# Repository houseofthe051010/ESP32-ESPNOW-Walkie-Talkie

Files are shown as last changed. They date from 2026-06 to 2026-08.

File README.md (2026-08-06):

Source: 

<p align="center">
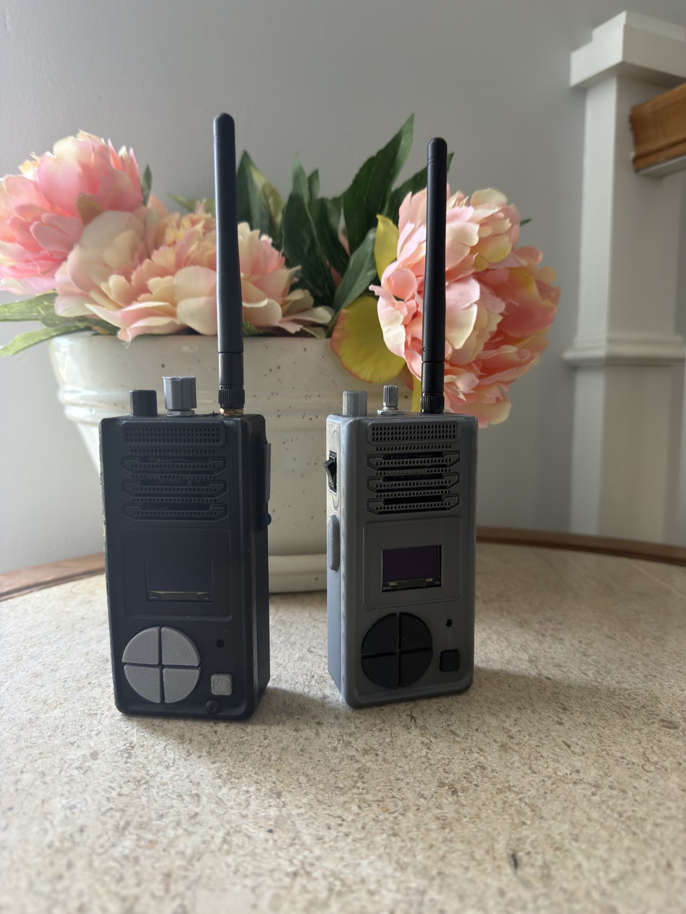
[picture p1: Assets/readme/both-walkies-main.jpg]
Both ESP32 walkie talkies side by side
  
</p>

## The Project

This is a ESP32 walkie talkie that uses WIFi (ESPNOW) for long range communication. It uses the esp32-wroom-32-U with an external U.fl connector, OLED 0.96 I2C display, I2S INMP441 microphone, I2S MAX98357A 3W speaker amplifier, 10k volume potentiometer, PTT button + 5 menu buttons, LASER, and LED. The aim of this walkie talkie was to not just serve as a walkie talkie, but sort of like a custom flipper zero that was more wireless oriented, although the walkie talkie comes with 3 female dupont pins that can be plugged in externally for a UART connection.

This device was framed as a walkie talkie but it can be used as a Wi-Fi/IoT device handheld controller platform. This is the main advantage with WIFI on esp32s as you can connect to a lot of places.

### Features

* ESP-NOW DIRECT VOICE (No router needed, multiple devices can connect)
* U.FL antenna for maximum range
* Tested to 600 meters of distance
* No acknowledge on ESPNOW, just shout and listen
* 16 kHz mono voice capture with IMA ADPCM compression
* No acknowledgement can be a problem with dropped packets so at weak ranges packets are automatically duplicated
* Built in black box logging with telemetry that can be uploaded to computer.
* OLED GUI with many features to control the walkie talkie and use as a remote for other wifi things.

<p align="center">
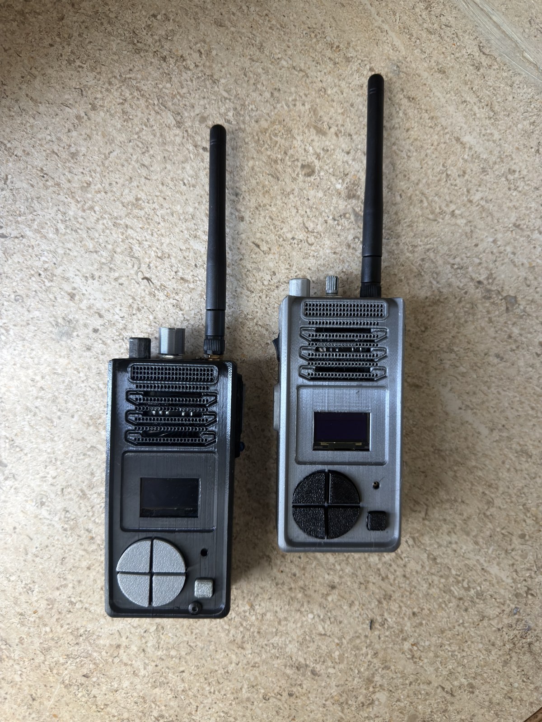
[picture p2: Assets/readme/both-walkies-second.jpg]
Second side-by-side photo of both ESP32 walkie talkies
  
</p>

## Walkie Talkie Hardware

The enclosure was designed to have enough space to solder every wire, but a custom PCB version was also made, scroll all the way down to learn more about fabricating PCB.

<p align="center">
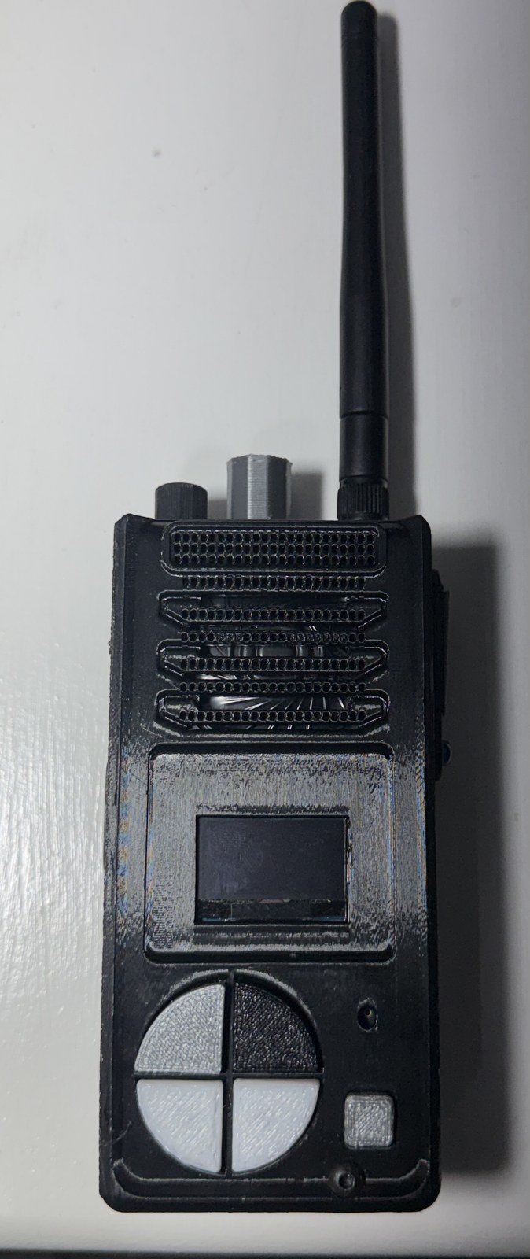
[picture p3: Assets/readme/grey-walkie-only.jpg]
Grey ESP32 walkie talkie
  
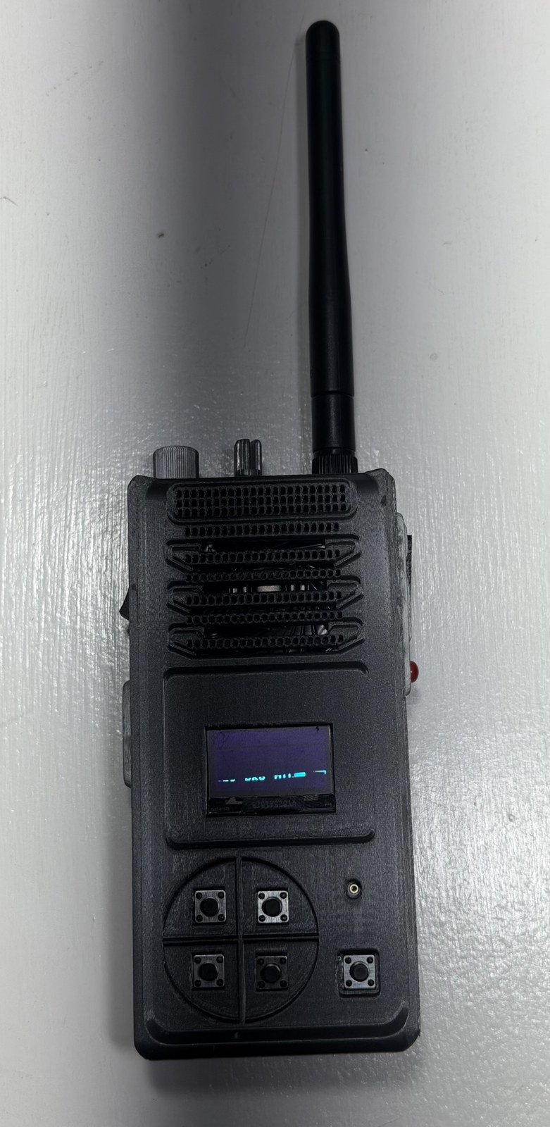
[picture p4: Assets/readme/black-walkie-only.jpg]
Black ESP32 walkie talkie
  
</p>

### Electronics

* ESP32WROOM32 U.FL
* OLED I2C 0.96'
* I2S INMP441 MIC
* 10K Volume potentiometer.
* 2000 MAH LIPO
* 6 push buttons
* 5mm LED light
* 5V laser module
* Voltage divider for ADC battery voltage measurment
* Main power switch

## Assembly Process

### 1. Printed enclosure

All these parts contribute to the final product

* [`walkie_talkie_bottom_case.stl`](SOURCE%20CAD/INDIVIDUAL%20STLS/walkie_talkie_bottom_case.stl)
* [`walkie_talkie_top_cover.stl`](SOURCE%20CAD/INDIVIDUAL%20STLS/walkie_talkie_top_cover.stl)
* [`walkie_talkie_top_buttons_grid.stl`](SOURCE%20CAD/INDIVIDUAL%20STLS/walkie_talkie_top_buttons_grid.stl)
* [`walkie_talkie_OK_button.stl`](SOURCE%20CAD/INDIVIDUAL%20STLS/walkie_talkie_OK_button.stl)
* [`walkie_talkie_PTT_button.stl`](SOURCE%20CAD/INDIVIDUAL%20STLS/walkie_talkie_PTT_button.stl)
* [`walkie_talkie_PTT_button_insert.stl`](SOURCE%20CAD/INDIVIDUAL%20STLS/walkie_talkie_PTT_button_insert.stl)

### 2. Power system

The battery powers the TP4056 which gives power to a boost converter than powers the entire device

1. Wire th TP4056 through the battery to the main switch to the boost convert and then to the esp32 VIN rail.

### 3. Electronics wiring

1. To make it easy and not messy, wire every component listed in the schematic to their respected GPIO and some pins might have multiple wires to them, thats fine.
2. Make sure to use heat shrink tape to avoid short circuits. 

### 4. Front-panel assembly

1. The LED and laser press into their  holes.
2. The PTT, OK, and four navigation buttons sit in the front-panel openings.
3. Insert the OLED
4. Secure all with super glue. Make sure to apply around perimeter and not damage the electronics.

### 5. Internal packing

1. Insert the electronics. One at a type, placing the esp32 underneath the TP4056 mount, and glueing each part to their holes.
2. The enclosure has enough space to accodomate addition UART connections if you want to connect something else later on.

### 6. ESP-IDF firmware loading

1. Fork the project and config with ESP-IDF to upload the code
2. Make sure you have experience with using powershell, open it

3. Init the powershell

   ```powershell
   idf.py set-target esp32
   ```

4. Open project using

   ```powershell
   idf.py menuconfig
   ```

6. Compile using

   ```powershell
   idf.py build
   ```

7. Flash using

   ```powershell
   idf.py flash monitor
   ```

## Circuit Diagram

<p align="center">
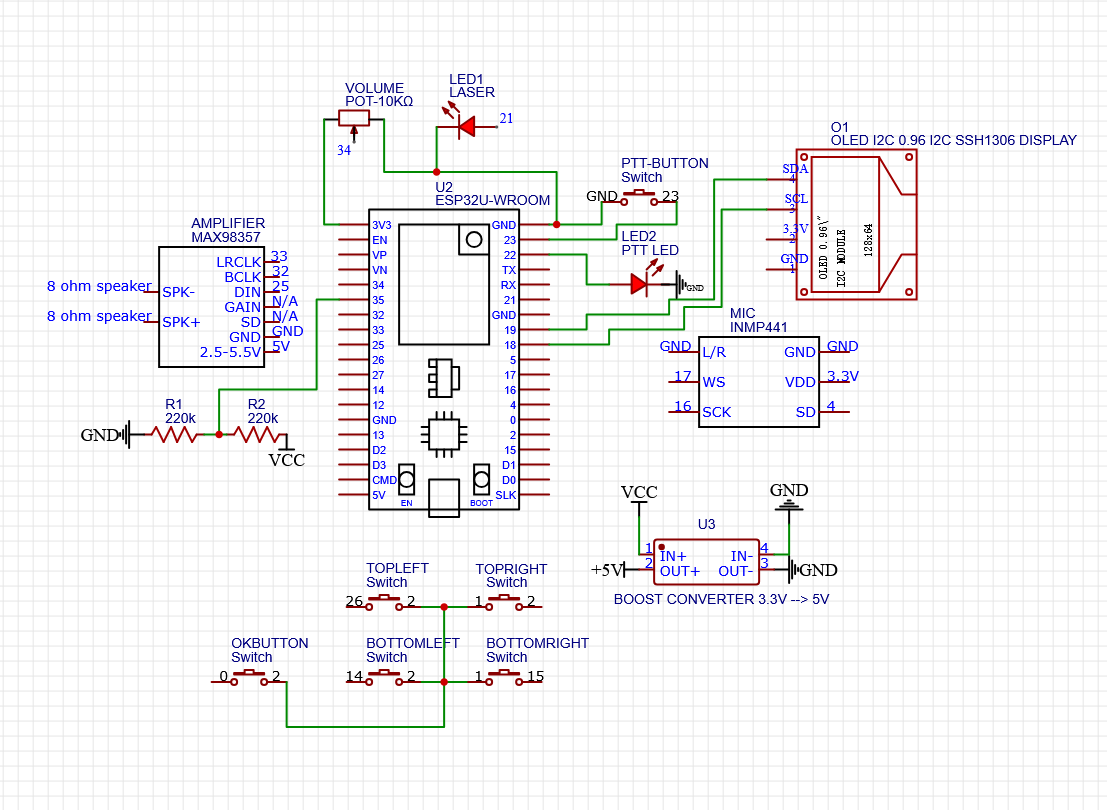
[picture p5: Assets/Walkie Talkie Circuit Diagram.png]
Walkie talkie circuit diagram
  
</p>

### Device PINOUT (Use when soldering)

| Function | ESP32 GPIO |
| --- | ---: |
| OLED SCL | GPIO18 |
| OLED SDA | GPIO19 |
| Speaker BCLK | GPIO32 |
| Speaker WS/LRC | GPIO33 |
| Speaker DIN | GPIO25 |
| Microphone BCLK | GPIO16 |
| Microphone WS | GPIO17 |
| Microphone SD | GPIO4 |
| OK button | GPIO0 |
| Bottom-left button | GPIO14 |
| Bottom-right button  | GPIO15 |
| Laser | GPIO21 |
| Volume potentiometer | GPIO34 |
| Battery divider | GPIO35 |

## My versions:

## Grey Walkie

<p align="center">
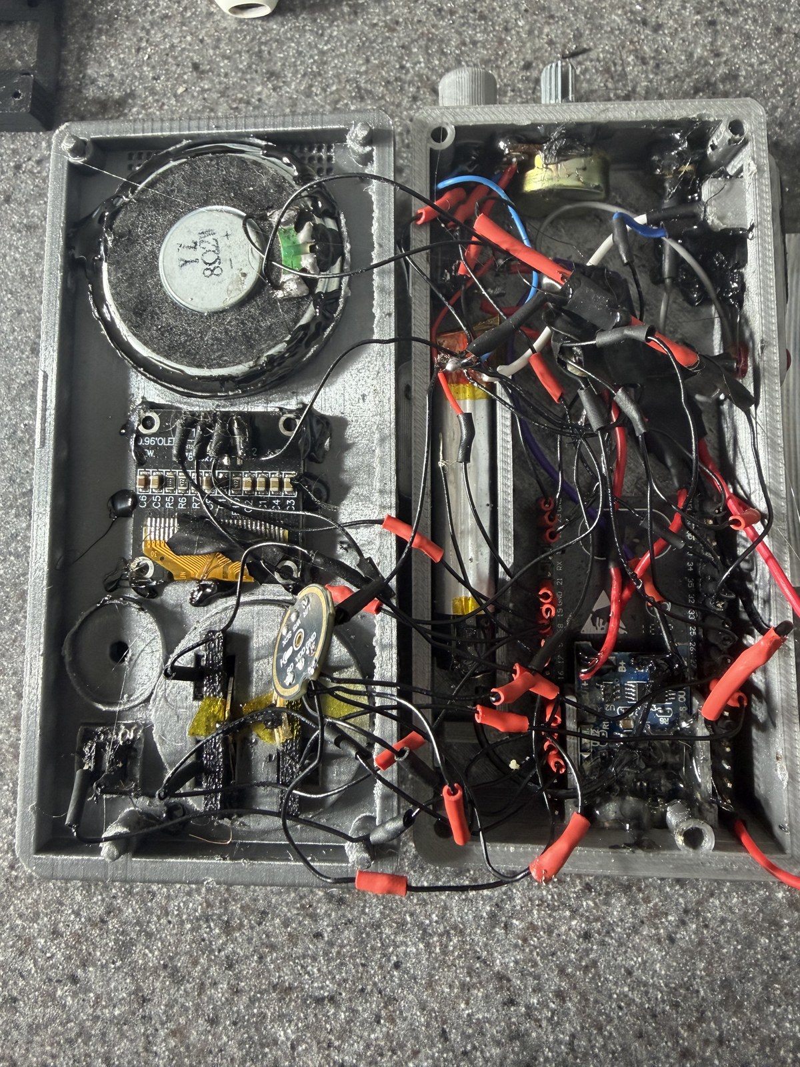
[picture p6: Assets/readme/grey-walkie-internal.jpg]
Grey walkie internal circuitry
  
</p>

This is my 2nd iteration with much cleaner wiring

## Black Walkie

<p align="center">
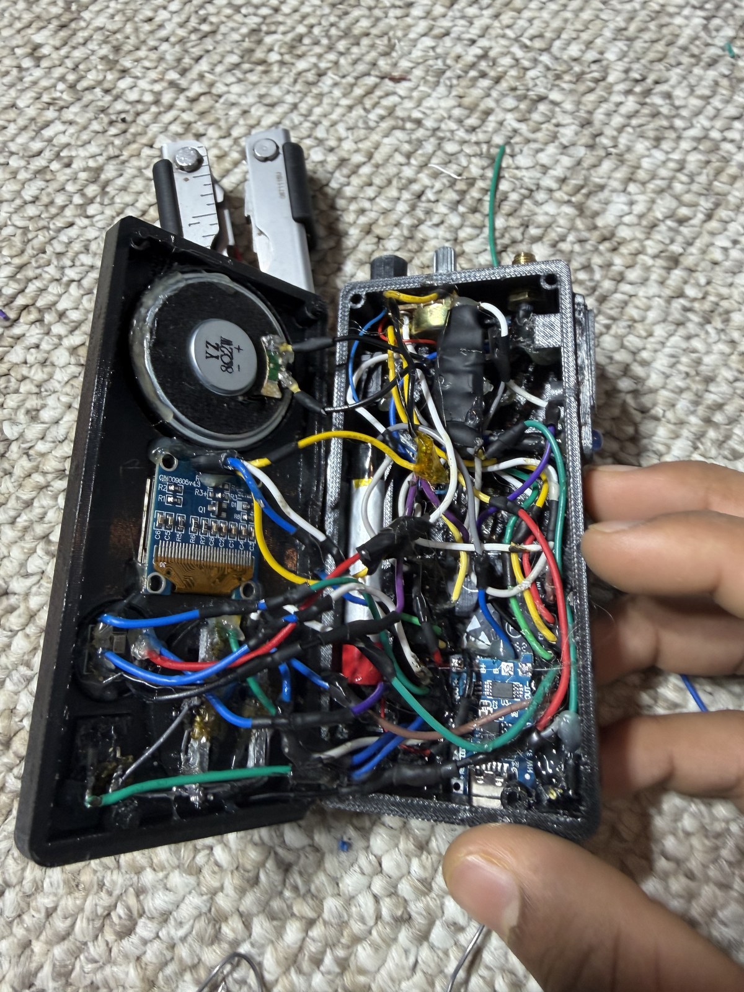
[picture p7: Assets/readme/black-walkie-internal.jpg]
Black walkie internal circuitry
  
</p>

This first iteration is much more messier

### User Interface

The user interface has a whole "apps" menu for different wifi connections and button use cases, you can code your own for your own custom use cases.

<p align="center">
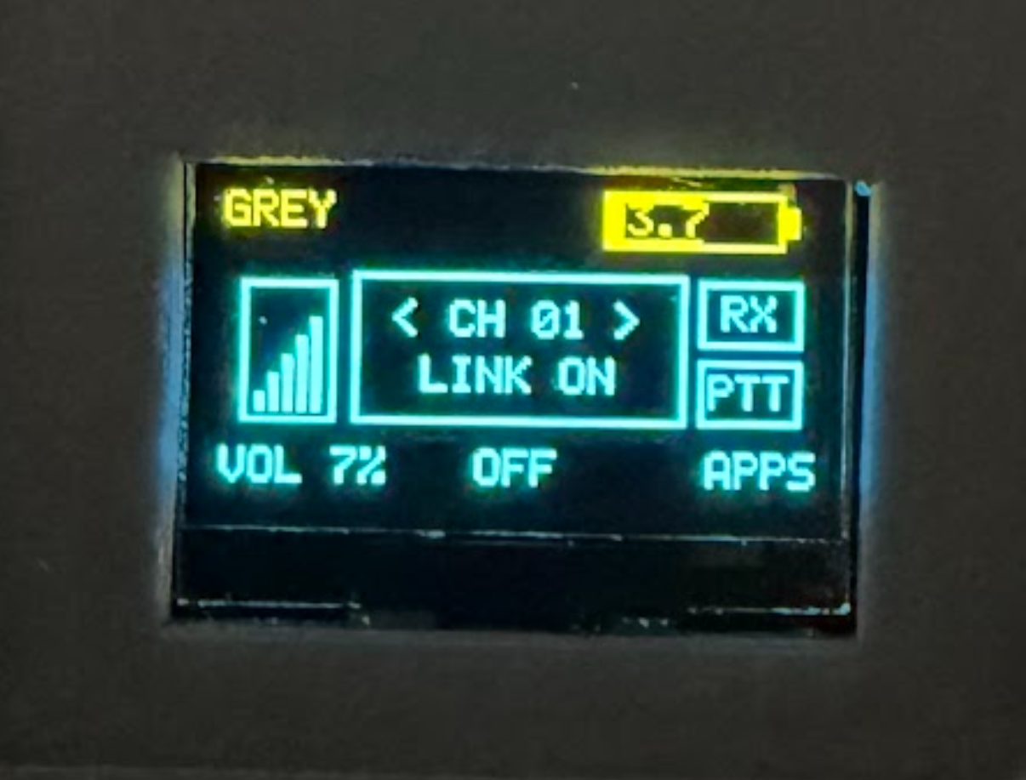
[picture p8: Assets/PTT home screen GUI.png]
Real OLED PTT home screen GUI
  
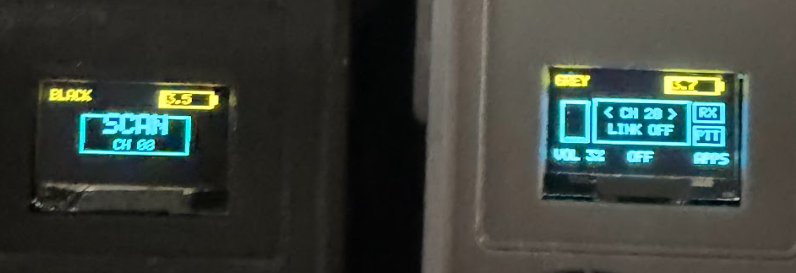
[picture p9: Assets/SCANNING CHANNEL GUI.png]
Real OLED scanning channel GUI
  
</p>

<p align="center">
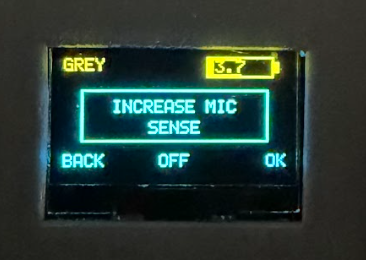
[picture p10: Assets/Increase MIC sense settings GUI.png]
Real OLED increase mic sensitivity settings GUI
  
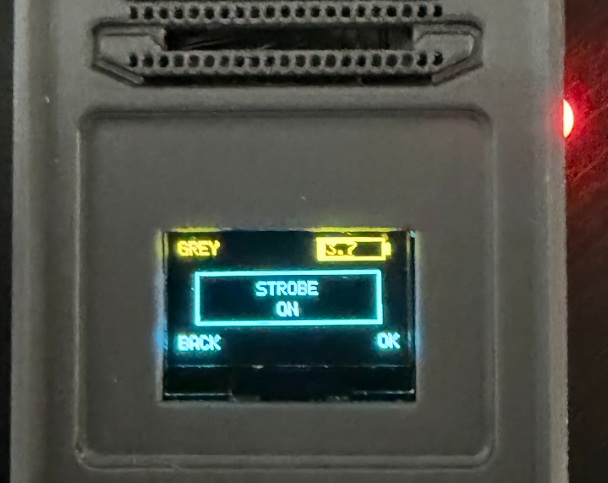
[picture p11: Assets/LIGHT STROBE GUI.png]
Real OLED light strobe app GUI
  
</p>

### Black Box

You can debug or see what happend with the walkie in the field, this isn't really needed now that I have perfected the code though, but can be helpful if you're making your own changes.

Example of a JSON black box record:

```json
{"event":"radio_stats","t_ms":123456,"board":"BLACK","ch":1,"ptt":false,"link":true,"rssi_dbm":-82,"quality_pct":21,"jitter_frames":3,"vol_pct":50,"tx_audio":0,"tx_audio_dup":0,"tx_ctrl":2,"tx_no_mem":0,"tx_fail":0,"rx_audio":48,"rx_audio_dup":7,"rx_audio_old":0,"rx_plc":2,"rx_ctrl":1,"rx_wrong_peer":0,"rx_bad_proto":0,"rx_wrong_channel":0}
```

## Bill of Materials

| Category | Quantity | Part | Purchase Link | Estimated Price |
| --- | ---: | --- | --- | ---: |
| Fabricated  | 2 | Walkie-talkie enclosure | [AliExpress](https://www.aliexpress.us/item/3256806989098121.html) | $2.22 |
| Electronics | 2 | ESP32 development board | [AliExpress](https://www.aliexpress.us/item/3256807617923920.html) | $1.90 |
| Radio | 2 | External antenna | [AliExpress](https://www.aliexpress.us/item/3256812004598286.html) | $0.64 used |
| Display | 2 | 0.96-inch OLED display | [AliExpress](https://www.aliexpress.us/item/3256805954920554.html) | $1.98 used |
| Audio | 2 | I2S microphone | [AliExpress](https://www.aliexpress.us/item/3256810210666726.html) | $6.45 |
| Audio | 2 | I2S speaker amplifier | [AliExpress](https://www.aliexpress.us/item/3256809715431644.html) | $1.88 used |
| Audio | 2 | Speaker | [AliExpress](https://www.aliexpress.us/item/3256805151989671.html) | $0.99 |
| Control | 2 | Volume potentiometer | [AliExpress](https://www.aliexpress.us/item/3256805703535495.html) | $0.99 |
| Power | 2 | Lithium battery | [AliExpress](https://www.aliexpress.us/item/3256811489152615.html) | $10.96 used |
| Power | 2 | Battery charger and protection board | [AliExpress](https://www.aliexpress.us/item/3256809139500038.html) | $0.20 used |
| Power | 2 | Boost converter | [AliExpress](https://www.aliexpress.us/item/3256811757076890.html) | $1.88 used |
| Power | 2 | Main power switch | [AliExpress](https://www.aliexpress.us/item/3256809823421130.html) | $2.37 |
| Lighting | 2 | Status LED | [AliExpress](https://www.aliexpress.us/item/3256807537207911.html) | $0.02 used |
| Lighting | 2 | Laser module | [AliExpress](https://www.aliexpress.us/item/3256808318801769.html) | $0.99 |
| Control | 12 | Momentary pushbutton | [AliExpress](https://www.aliexpress.us/item/3256810479380665.html) | $0.99 |
| Optional RC | 2 | Continuous-rotation servo | [AliExpress](https://www.aliexpress.us/item/3256804365417662.html) | $9.28 |
| Measurement | 2 | 100 kΩ battery-divider resistor | [AliExpress](https://www.aliexpress.us/item/3256802303553096.html) | $0.02 used |
| Measurement | 2 | 220 kΩ battery-divider resistor | [AliExpress](https://www.aliexpress.us/item/3256802303553096.html) | $0.02 used |
| Wiring | 1 | Signal and power wire | [AliExpress](https://www.aliexpress.us/item/3256810394181790.html) | $0.99 allowance |

## Custom PCB Fabrication Option

If you want to avoid the hassle of soldering than fabricate your own PCB here: 

See [CUSTOM PCB FABRICATION/README.md](CUSTOM%20PCB%20FABRICATION/README.md) for the JLBPCB fabrication guide

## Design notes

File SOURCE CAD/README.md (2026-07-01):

# Walkie Talkie CAD Files

This folder is reserved for the open-source mechanical design files for the ESP32 walkie-talkie.

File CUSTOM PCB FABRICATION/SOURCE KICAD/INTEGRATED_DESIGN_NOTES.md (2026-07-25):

# Integrated WalkieTalkie schematic

This revision replaces the ESP32 DevKit, TP4056 breakout and MAX98357A
breakout with manufacturer-assembled components.

## Project files

- `WalkieTalkie.kicad_sch` — main/lower PCBA schematic.
- `WalkieTalkie_Front.kicad_sch` — front/user-interface PCBA schematic.
- `WalkieTalkie_JLCPCB.kicad_sym` — project symbol library imported from
  JLCPCB/EasyEDA part records.
- `WalkieTalkie_JLCPCB.pretty` — matching project footprints.
- `WalkieTalkie_JLCPCB.3dshapes` — imported 3D models.
- `JLCPCB_ASSEMBLY_PARTS.csv` — selected major assembly parts and LCSC IDs.

## Important design behavior

- The ESP32-WROOM-32U contains its own U.FL/IPEX antenna connector.
- USB-C VBUS feeds the TP4056 charger and the system load-sharing path.
- USB D+/D- feed a CH340C USB-to-UART bridge. This revision uses manual
  BOOT and RESET buttons instead of the more failure-prone auto-download
  transistor circuit.
- The TP4056 charge current is set near 500 mA with a 2.4 kOhm PROG resistor.
- DW01A + FS8205A provide single-cell protection.
- TPS63031 provides regulated 3.3 V across the normal single-cell range.
- MAX98357A runs from VSYS. Its two speaker pads are a bridge output; neither
  pad is ground.
- R20-R23 are fitted for the Black firmware mapping. R24-R27 are DNP.
  Reverse those two groups for the Grey mapping.

## Hand-soldered parts

The main schematic intentionally uses large plated solder-wire pads for:

- J4: two speaker wires.
- J5: three potentiometer wires.
- J6: two push-to-talk button wires.
- J7: two external status-LED wires.
- J8: two laser-module wires.

The five face buttons are SMD parts on the front PCB and are intended for
manufacturer assembly.

## Before ordering

The OLED part is wave-solder/high-difficulty and the INMP441 listing may
require Standard PCBA or pre-ordering into the JLCPCB private parts library.
Recheck stock and price when ordering. Confirm all imported footprints against
the current manufacturer datasheets before routing or production.

The older breakout-module PCB files and reports are preserved in
`Previous_Breakout_Draft`. Create fresh PCB files after setting the enclosure
dimensions.

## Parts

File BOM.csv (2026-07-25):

Category | Quantity | Part | Link | Price
Fabricated | 2 | Walkie-talkie enclosure | https://www.aliexpress.us/item/3256806989098121.html | $2.22
Electronics | 2 | ESP32 development board | https://www.aliexpress.us/item/3256807617923920.html | $1.90
Radio | 2 | External antenna | https://www.aliexpress.us/item/3256812004598286.html | $0.64 used
Display | 2 | OLED display | https://www.aliexpress.us/item/3256805954920554.html | $1.98 used
Audio | 2 | I2S microphone | https://www.aliexpress.us/item/3256810210666726.html | $6.45
Audio | 2 | I2S speaker amplifier | https://www.aliexpress.us/item/3256809715431644.html | $1.88 used
Audio | 2 | Speaker | https://www.aliexpress.us/item/3256805151989671.html | $0.99
Control | 2 | Volume potentiometer | https://www.aliexpress.us/item/3256805703535495.html | $0.99
Power | 2 | Lithium battery | https://www.aliexpress.us/item/3256811489152615.html | $10.96 used
Power | 2 | Battery charger and protection board | https://www.aliexpress.us/item/3256809139500038.html | $0.20 used
Power | 2 | Boost converter | https://www.aliexpress.us/item/3256811757076890.html | $1.88 used
Power | 2 | Main power switch | https://www.aliexpress.us/item/3256809823421130.html | $2.37
Lighting | 2 | Status LED | https://www.aliexpress.us/item/3256807537207911.html | $0.02 used
Lighting | 2 | Laser module | https://www.aliexpress.us/item/3256808318801769.html | $0.99
Control | 12 | Momentary pushbutton | https://www.aliexpress.us/item/3256810479380665.html | $0.99
Optional RC | 2 | Continuous-rotation servo | https://www.aliexpress.us/item/3256804365417662.html | $9.28
Measurement | 2 | 100-kilohm battery-divider resistor | https://www.aliexpress.us/item/3256802303553096.html | $0.02 used
Measurement | 2 | 220-kilohm battery-divider resistor | https://www.aliexpress.us/item/3256802303553096.html | $0.02 used
Wiring | 1 | Signal and power wire | https://www.aliexpress.us/item/3256810394181790.html | $0.99 allowance

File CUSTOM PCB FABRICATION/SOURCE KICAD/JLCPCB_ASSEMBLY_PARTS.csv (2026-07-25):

Board | References | Qty | Manufacturer Part | LCSC | Assembly | Notes
Main | U1 | 1 | ESP32-WROOM-32U-N4 | C328062 | SMT | 4 MB ESP32 module with factory U.FL/IPEX antenna socket
Main | J1 | 1 | TYPE-C-31-M-12 | C165948 | SMT | 16-pin USB-C receptacle
Main | U4 | 1 | CH340C | C84681 | SMT | USB-to-UART; no external crystal required
Main | U5 | 1 | TP4056 | C20199357 | SMT | Low-cost ESOP-8 1-cell 4.2 V charger
Main | U6 | 1 | DW01A | C351410 | SMT | Single-cell protection controller
Main | Q1 | 1 | FS8205A | C2830320 | SMT | Back-to-back battery protection MOSFETs
Main | U3 | 1 | ME6211C33M5G-N | C82942 | SMT | 3.3 V regulator dedicated to CH340C
Main | U7 | 1 | TPS63031DSKR | C15516 | SMT | Fixed 3.3 V, 900 mA buck-boost for ESP32 and front board
Main | U8 | 1 | MAX98357AETE+T | C910544 | SMT | 3.2 W I2S class-D amplifier, TQFN-16
Main | J3 | 1 | AFC01-S16FCC-00 | C262272 | SMT | 16-pin 0.5 mm bottom-contact FFC connector
Front | J201 | 1 | AFC01-S16FCC-00 | C262272 | SMT | 16-pin 0.5 mm bottom-contact FFC connector
Front | SW201-SW205 | 5 | TS-1088R-02026 | C455280 | SMT | 4 x 3 mm SMD tactile switch
Front | U202 | 1 | INMP441ACEZ | C9900011556 | SMT | LGA-9 I2S microphone; Standard PCBA/private stock may be required
Front | U201 | 1 | HS96L03W2C03 | C5248080 | Wave/Standard | 0.96-inch 128x64 I2C OLED; wave-solder/high-difficulty assembly
Main | J4-J8 | 5 | Solder wire pads | N/A | Hand solder | Potentiometer, speaker, PTT, LED and laser

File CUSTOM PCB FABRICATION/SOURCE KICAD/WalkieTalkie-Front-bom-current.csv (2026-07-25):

Refs | Value | Footprint | MPN | LCSC | DNP
C201,C203 | 100nF | Capacitor_SMD:C_0603_1608Metric
C202,C204 | 10uF | Capacitor_SMD:C_0805_2012Metric
J201 | MAIN BOARD FFC | WalkieTalkie_JLCPCB:FPC-SMD_P0.50-16P_FGS-XJ-H2.0 | AFC01-S16FCC-00 | C262272
R201,R202 | 4.7k | Resistor_SMD:R_0603_1608Metric |  |  | No
SW201 | OK | WalkieTalkie_JLCPCB:SW-SMD_L3.9-W3.0-P4.45 | TS-1088R-02026 | C455280
SW202 | TOP LEFT | WalkieTalkie_JLCPCB:SW-SMD_L3.9-W3.0-P4.45 | TS-1088R-02026 | C455280
SW203 | TOP RIGHT | WalkieTalkie_JLCPCB:SW-SMD_L3.9-W3.0-P4.45 | TS-1088R-02026 | C455280
SW204 | BOTTOM LEFT | WalkieTalkie_JLCPCB:SW-SMD_L3.9-W3.0-P4.45 | TS-1088R-02026 | C455280
SW205 | BOTTOM RIGHT | WalkieTalkie_JLCPCB:SW-SMD_L3.9-W3.0-P4.45 | TS-1088R-02026 | C455280
U201 | HS96L03W2C03 0.96 OLED | WalkieTalkie_JLCPCB:OLED-TH_L27.8-W27.2-P2.54_C9900033791 | HS96L03W2C03 | C5248080
U202 | INMP441ACEZ | WalkieTalkie_JLCPCB:MID-SMD_L4.7-W3.8_INMP441ACEZ | INMP441ACEZ | C9900011556

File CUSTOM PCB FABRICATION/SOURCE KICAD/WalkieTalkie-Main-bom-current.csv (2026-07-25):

Refs | Value | Footprint | MPN | LCSC | DNP
C1,C2,C11 | 1uF | Capacitor_SMD:C_0805_2012Metric
C3,C6,C12,C14,C16 | 100nF | Capacitor_SMD:C_0603_1608Metric
C4,C5,C7-C10,C13,C15 | 10uF | Capacitor_SMD:C_0805_2012Metric
D1 | SS34 | Diode_SMD:D_SMA | SS34 | C8678
D2 | RED CHARGING | LED_SMD:LED_0603_1608Metric
D3 | GREEN FULL | LED_SMD:LED_0603_1608Metric
J1 | TYPE-C-31-M-12 | WalkieTalkie_JLCPCB:USB-C_SMD-TYPE-C-31-M-12_1 | TYPE-C-31-M-12 | C165948
J2 | BATTERY JST-PH | WalkieTalkie_JLCPCB:CONN-SMD_P2.00_S2B-PH-SM4-TB-LF-SN | S2B-PH-SM4-TB(LF)(SN) | C295747
J3 | FRONT BOARD FFC | WalkieTalkie_JLCPCB:FPC-SMD_P0.50-16P_FGS-XJ-H2.0 | AFC01-S16FCC-00 | C262272
J4 | SPEAKER WIRES | Connector_Wire:SolderWire-0.25sqmm_1x02_P4.2mm_D0.65mm_OD1.7mm_Relief
J5 | 10k POTENTIOMETER | Connector_Wire:SolderWire-0.15sqmm_1x03_P4mm_D0.5mm_OD1.5mm_Relief
J6 | PTT BUTTON | Connector_Wire:SolderWire-0.25sqmm_1x02_P4.2mm_D0.65mm_OD1.7mm_Relief
J7 | EXTERNAL LED | Connector_Wire:SolderWire-0.25sqmm_1x02_P4.2mm_D0.65mm_OD1.7mm_Relief
J8 | LASER WIRES | Connector_Wire:SolderWire-0.25sqmm_1x02_P4.2mm_D0.65mm_OD1.7mm_Relief
L1 | 2.2uH >=2A | Inductor_SMD:L_0805_2012Metric
Q1 | FS8205A | WalkieTalkie_JLCPCB:SOT-23-6_L2.9-W1.6-P0.95-LS2.8-BR | FS8205A | C2830320
Q2 | AO3401A | Package_TO_SOT_SMD:SOT-23 | AO3401A | C15127
Q3 | AO3400A | Package_TO_SOT_SMD:SOT-23 | AO3400A | C20917
R1,R2 | 5.1k | Resistor_SMD:R_0603_1608Metric |  |  | No
R3 | 2.4k (500mA) | Resistor_SMD:R_0603_1608Metric |  |  | No
R4,R5,R7 | 1k | Resistor_SMD:R_0603_1608Metric |  |  | No
R6 | 100R | Resistor_SMD:R_0603_1608Metric |  |  | No
R8,R10,R11 | 10k | Resistor_SMD:R_0603_1608Metric |  |  | No
R9,R12,R15 | 100k | Resistor_SMD:R_0603_1608Metric |  |  | No
R13 | 1M | Resistor_SMD:R_0603_1608Metric |  |  | No
R14 | 330R | Resistor_SMD:R_0603_1608Metric |  |  | No
R20-R23 | 0R BLACK | Resistor_SMD:R_0603_1608Metric |  |  | No
R24-R27 | 0R GREY | Resistor_SMD:R_0603_1608Metric |  |  | Yes
R28,R29 | 220k | Resistor_SMD:R_0603_1608Metric |  |  | No
SW1 | RESET | WalkieTalkie_JLCPCB:SW-SMD_L3.9-W3.0-P4.45 | TS-1088R-02026 | C455280
SW2 | BOOT | WalkieTalkie_JLCPCB:SW-SMD_L3.9-W3.0-P4.45 | TS-1088R-02026 | C455280
U1 | ESP32-WROOM-32U-N4 | WalkieTalkie_JLCPCB:WIFIM-SMD_38P-L19.2-W18.0-P1.27 | ESP32-WROOM-32U-N4 | C328062
U2 | USBLC6-2SC6 | Package_TO_SOT_SMD:SOT-23-6 | USBLC6-2SC6 | C7519
U3 | ME6211C33M5G-N | WalkieTalkie_JLCPCB:SOT-23-5_L3.0-W1.7-P0.95-LS2.8-BL | ME6211C33M5G-N | C82942
U4 | CH340C | WalkieTalkie_JLCPCB:SOP-16_L10.0-W3.9-P1.27-LS6.0-BL | CH340C | C84681
U5 | TP4056 | WalkieTalkie_JLCPCB:ESOP-8_L4.9-W3.9-P1.27-LS6.0-BL-EP-4 | TP4056 | C20199357
U6 | DW01A | WalkieTalkie_JLCPCB:SOT-23-6_L2.9-W1.6-P0.95-LS2.8-BL | DW01A | C351410
U7 | TPS63031DSKR | WalkieTalkie_JLCPCB:SON-10_L2.5-W2.5-P0.50-TL-EP | TPS63031DSKR | C15516
U8 | MAX98357AETE+T | WalkieTalkie_JLCPCB:TQFN-16_L3.0-W3.0-P0.50-BL-EP1.5 | MAX98357AETE+T | C910544

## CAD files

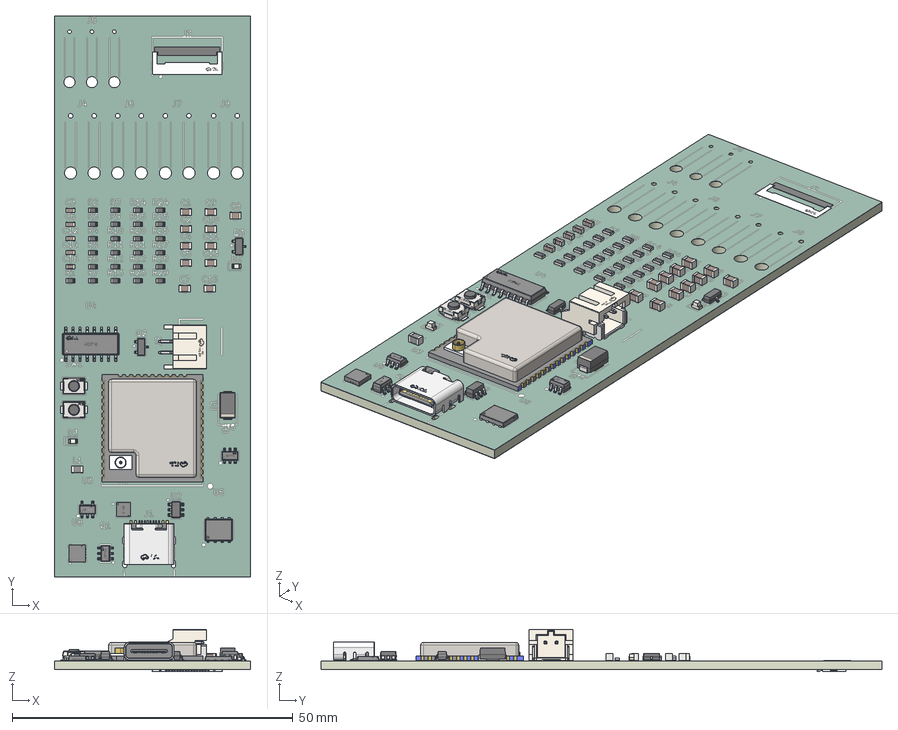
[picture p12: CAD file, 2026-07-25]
CUSTOM PCB FABRICATION/SOURCE KICAD/walkiemainbaord.step
35.0 x 100.0 x 7.50 mm
C_0805_2012Metric x 11
FPC-SMD_P0.50-16P_FGS-XJ-H2.0
R_0603_1608Metric x 25
TQFN-16_L3.0-W3.0-P0.50-BL-EP1.5
SON-10_L2.5-W2.5-H0.8-P0.50
SOT-23 x 2
LED_0603_1608Metric x 2
C_0603_1608Metric x 5
SW-SMD_L3.9-W2.9-H2.0-LS4.8 x 2
SOT-23-6_L2.9-W1.6-H1.5-LS2.8-P0.95 x 2
L_0805_2012Metric
SOP-16_L9.9-W3.9-H1.5-LS6.0-P1.27
WIFIM-SMD_38P-L19.2-W18.0-H3.2-P1.27
USB-C_SMD-TYPE-C-31-M-12
SOT-23-6
D_SMA
SOT-23-5_L2.9-W1.6-H1.1-LS2.8-P0.95
CONN-SMD_P2.00_S2B-PH-SM4-TB-LF-SN
ESOP-8_L4.9-W3.9-P1.27-LS6.0-BL-EP-4
WalkieTalkie_silkscreen
WalkieTalkie_soldermask x 2
WalkieTalkie_PCB

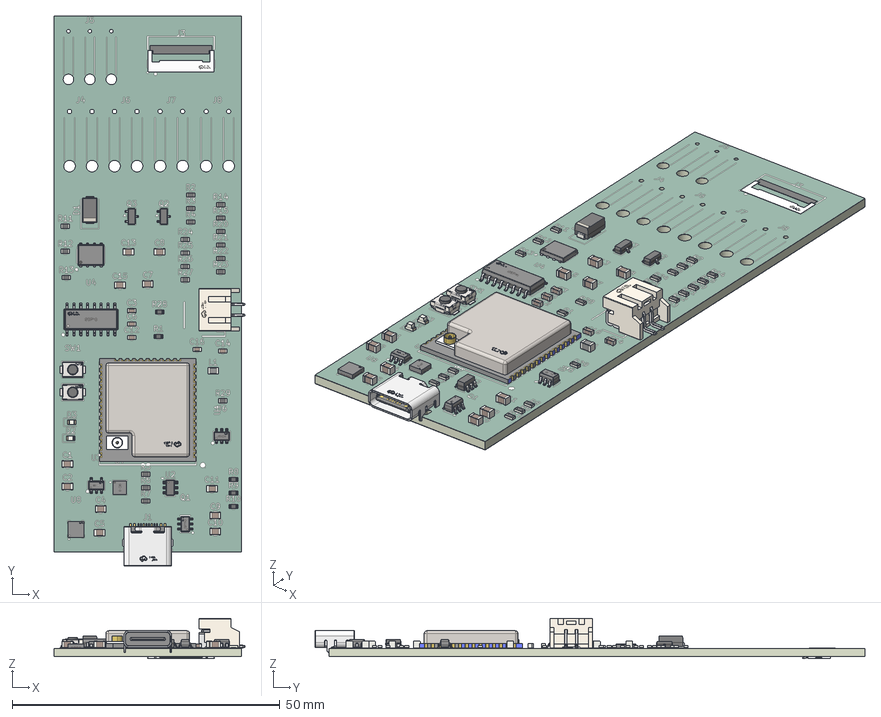
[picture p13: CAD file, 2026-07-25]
CUSTOM PCB FABRICATION/SOURCE KICAD/walkie2mainbaord.step
35.6 x 102.6 x 7.50 mm
C_0805_2012Metric x 11
FPC-SMD_P0.50-16P_FGS-XJ-H2.0
R_0603_1608Metric x 25
TQFN-16_L3.0-W3.0-P0.50-BL-EP1.5
SON-10_L2.5-W2.5-H0.8-P0.50
SOT-23 x 2
LED_0603_1608Metric x 2
C_0603_1608Metric x 5
SW-SMD_L3.9-W2.9-H2.0-LS4.8 x 2
SOT-23-6_L2.9-W1.6-H1.5-LS2.8-P0.95 x 2
L_0805_2012Metric
SOP-16_L9.9-W3.9-H1.5-LS6.0-P1.27
WIFIM-SMD_38P-L19.2-W18.0-H3.2-P1.27
USB-C_SMD-TYPE-C-31-M-12
SOT-23-6
D_SMA
SOT-23-5_L2.9-W1.6-H1.1-LS2.8-P0.95
CONN-SMD_P2.00_S2B-PH-SM4-TB-LF-SN
ESOP-8_L4.9-W3.9-P1.27-LS6.0-BL-EP-4
Wal8574_silkscreen
Wal8574_soldermask x 2
Wal8574_PCB

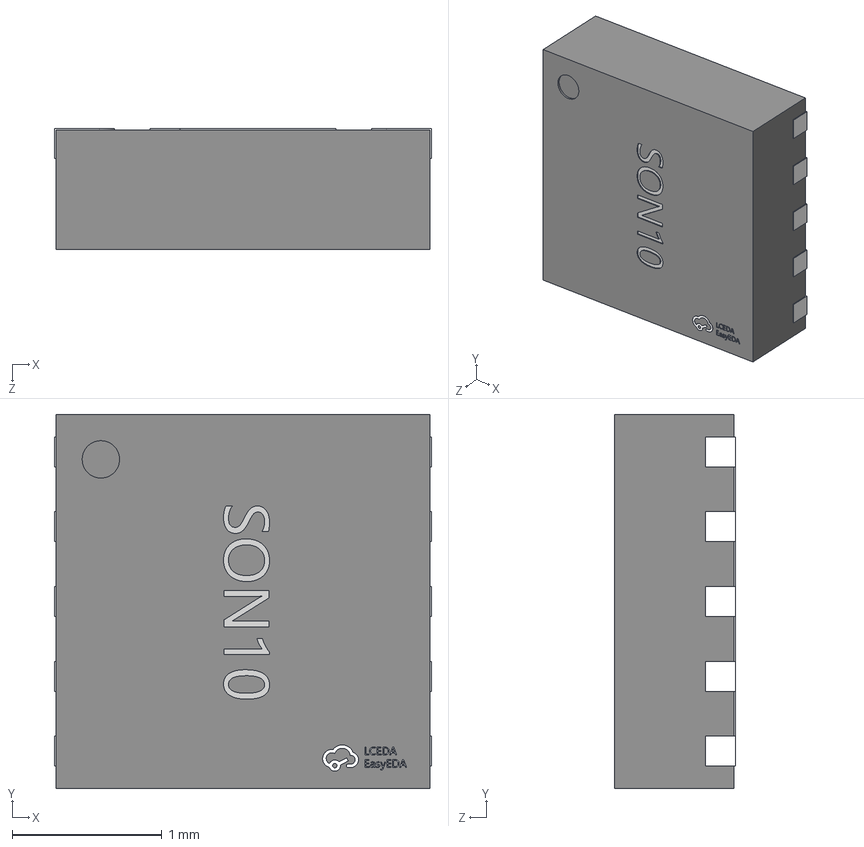
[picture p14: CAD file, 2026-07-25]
CUSTOM PCB FABRICATION/SOURCE KICAD/.easyeda_cache/12c631ea46604e478703d8e42e76d1d7.step
2.52 x 2.50 x 0.811 mm

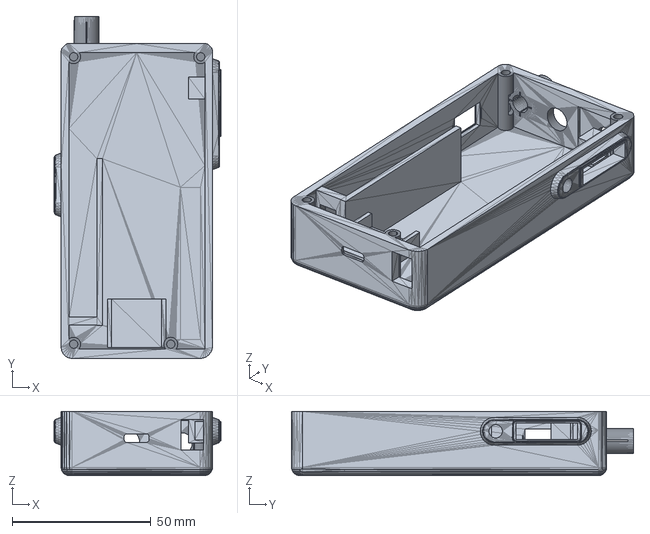
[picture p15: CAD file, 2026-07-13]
SOURCE CAD/INDIVIDUAL STLS/walkie_talkie_bottom_case.step
60.0 x 123.2 x 23.2 mm

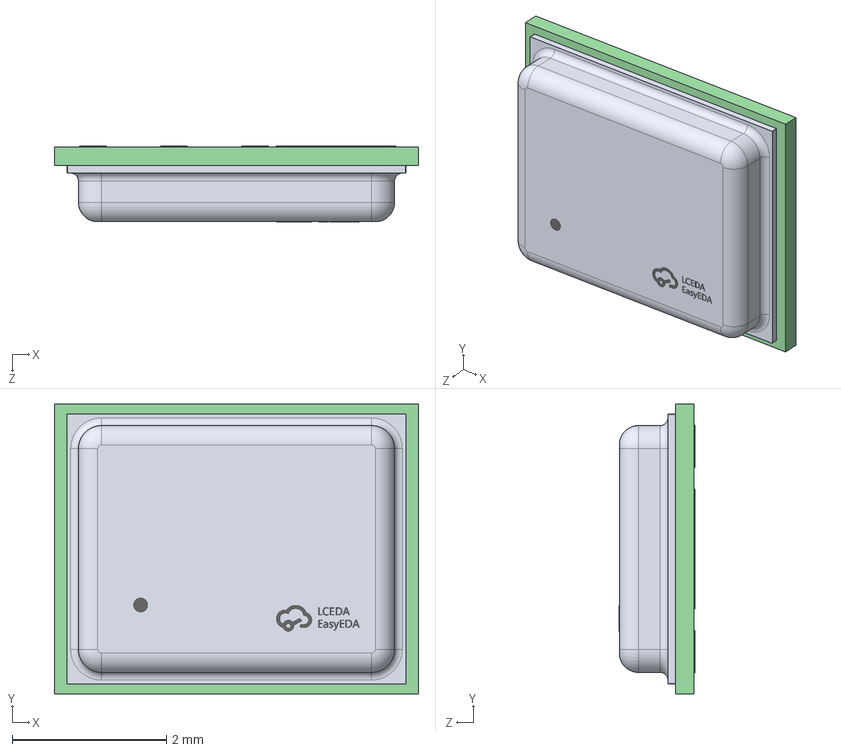
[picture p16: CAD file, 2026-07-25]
CUSTOM PCB FABRICATION/SOURCE KICAD/.easyeda_cache/c35e8a98ac4c4d8d9f4a5ff38194d268.step
4.72 x 3.76 x 0.981 mm

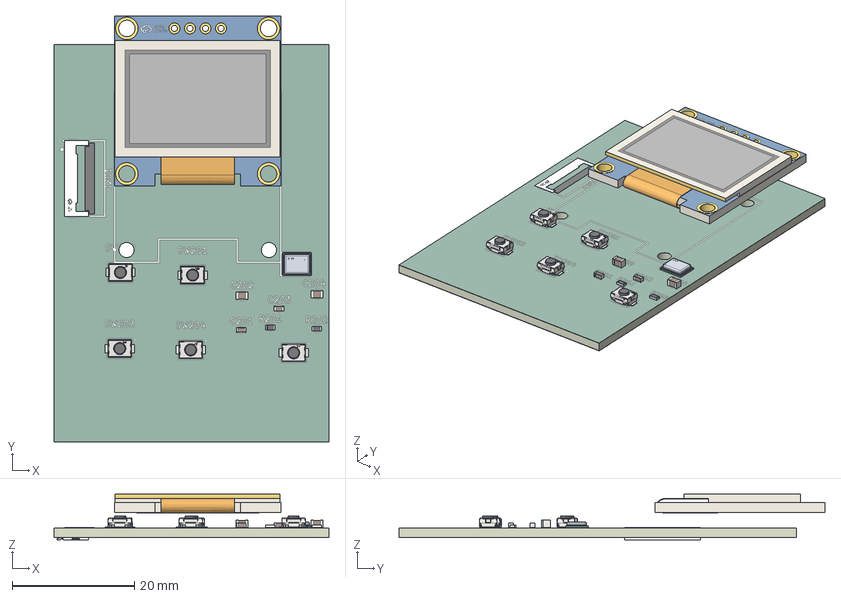
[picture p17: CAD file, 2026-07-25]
CUSTOM PCB FABRICATION/SOURCE KICAD/walkiefront.step
45.0 x 69.6 x 7.50 mm
OLED-TH_L27.8-W27.2-P2.54_C9900033791
C_0805_2012Metric x 2
SW-SMD_L3.9-W2.9-H2.0-LS4.8 x 5
R_0603_1608Metric x 2
FPC-SMD_P0.50-16P_FGS-XJ-H2.0
MID-SMD_L4.7-W3.8_INMP441ACEZ
C_0603_1608Metric x 2
Wal8ED3_silkscreen
Wal8ED3_soldermask x 2
Wal8ED3_PCB

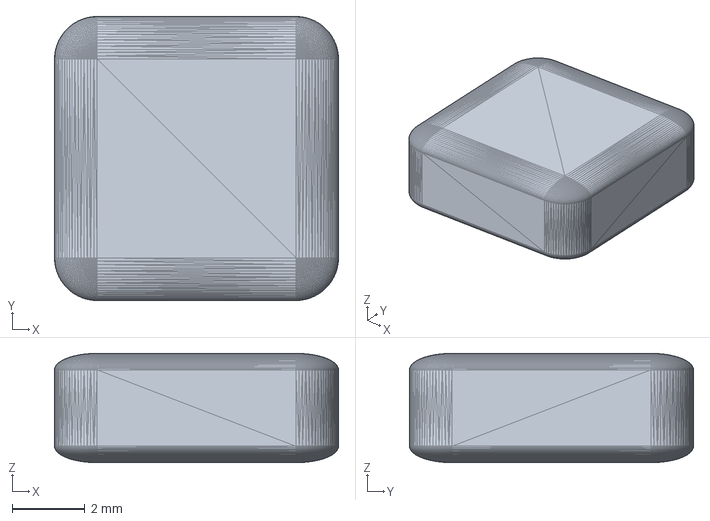
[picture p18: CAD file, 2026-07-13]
SOURCE CAD/INDIVIDUAL STLS/walkie_talkie_OK_button.step
7.80 x 7.80 x 3.00 mm

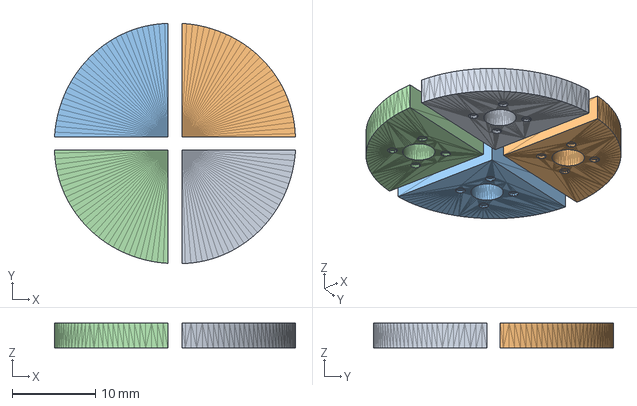
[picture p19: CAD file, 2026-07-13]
SOURCE CAD/INDIVIDUAL STLS/walkie_talkie_top_buttons_grid.step
29.0 x 28.9 x 3.00 mm

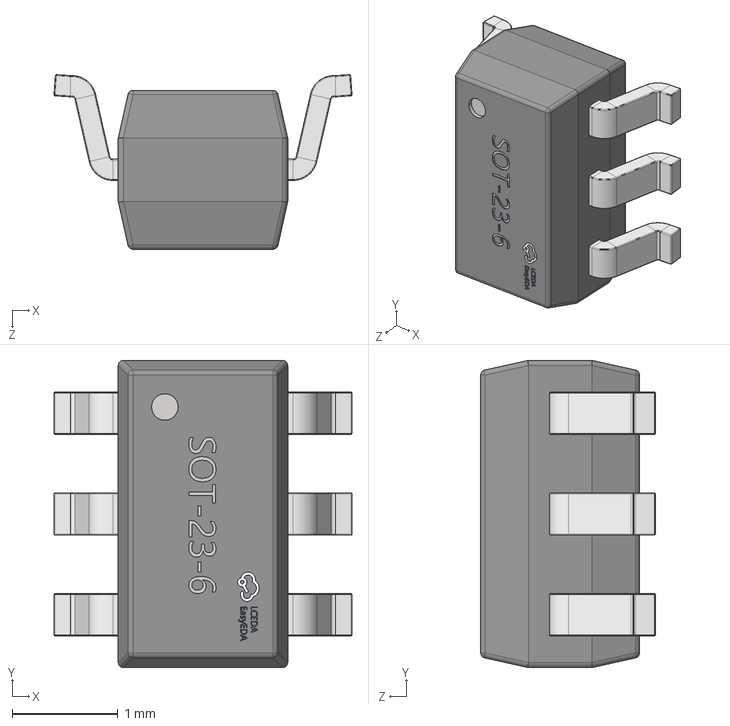
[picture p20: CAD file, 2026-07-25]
CUSTOM PCB FABRICATION/SOURCE KICAD/.easyeda_cache/229b69761e2c45dba6a83d8866dec72d.step
2.81 x 2.90 x 1.65 mm

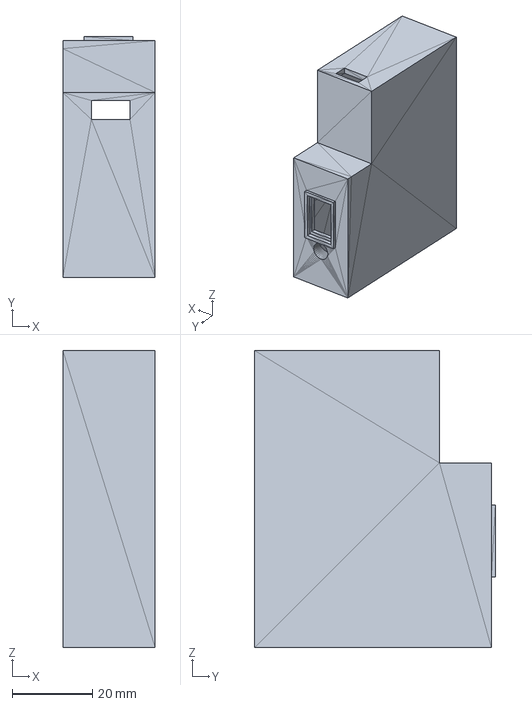
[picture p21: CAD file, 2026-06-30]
SOURCE CAD/INDIVIDUAL STLS/mnbvcx.step
23.0 x 60.0 x 74.0 mm

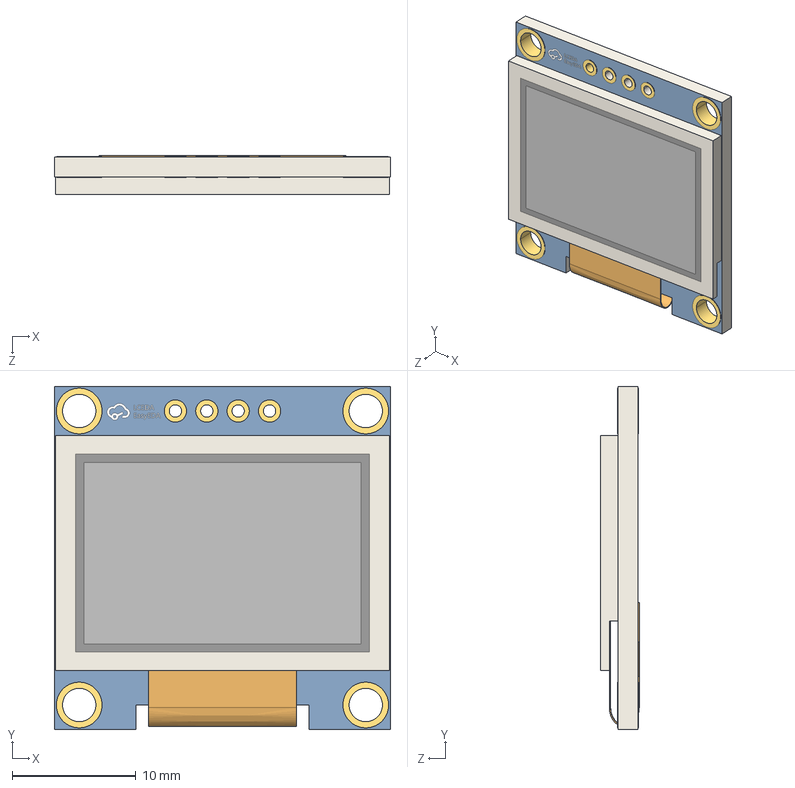
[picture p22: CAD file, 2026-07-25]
CUSTOM PCB FABRICATION/SOURCE KICAD/.easyeda_cache/c6b423183c2f4cf5a163f75f8ad52fae.step
27.2 x 27.8 x 3.12 mm

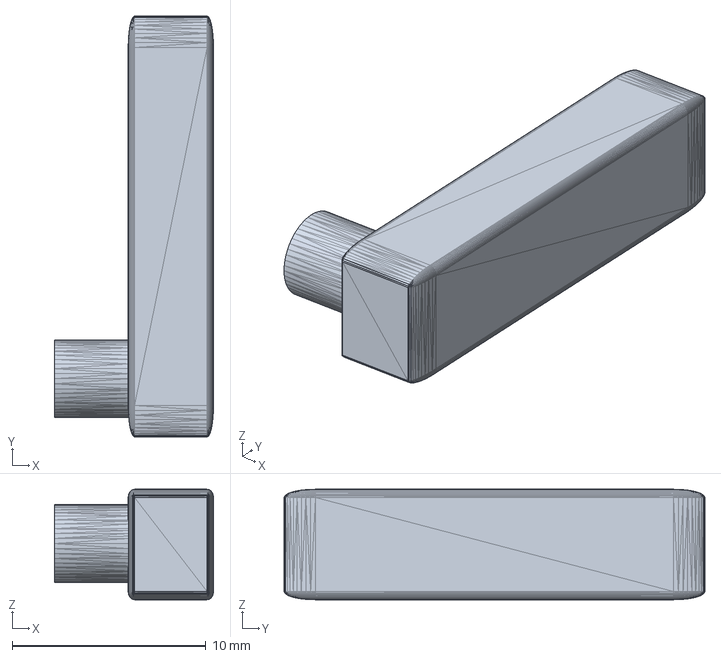
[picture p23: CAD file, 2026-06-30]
SOURCE CAD/INDIVIDUAL STLS/walkie_talkie_PTT_button.step
8.20 x 21.7 x 5.70 mm

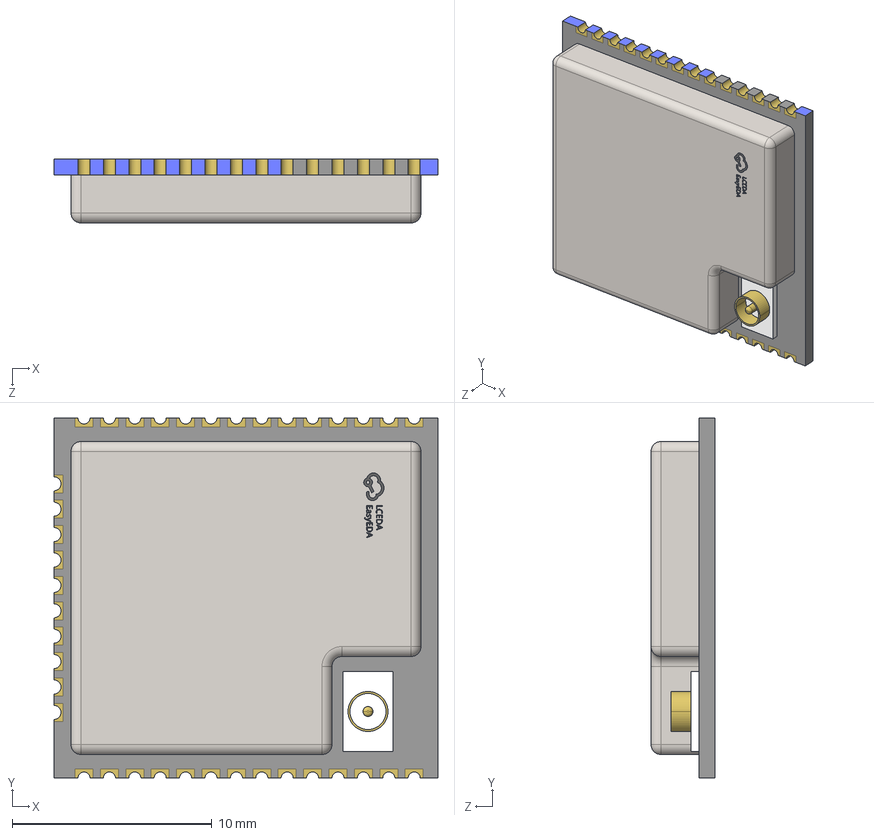
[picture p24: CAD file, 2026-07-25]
CUSTOM PCB FABRICATION/SOURCE KICAD/.easyeda_cache/4bfedb4f78ee4d6a8d7a8c81210d6f34.step
19.2 x 18.0 x 3.20 mm

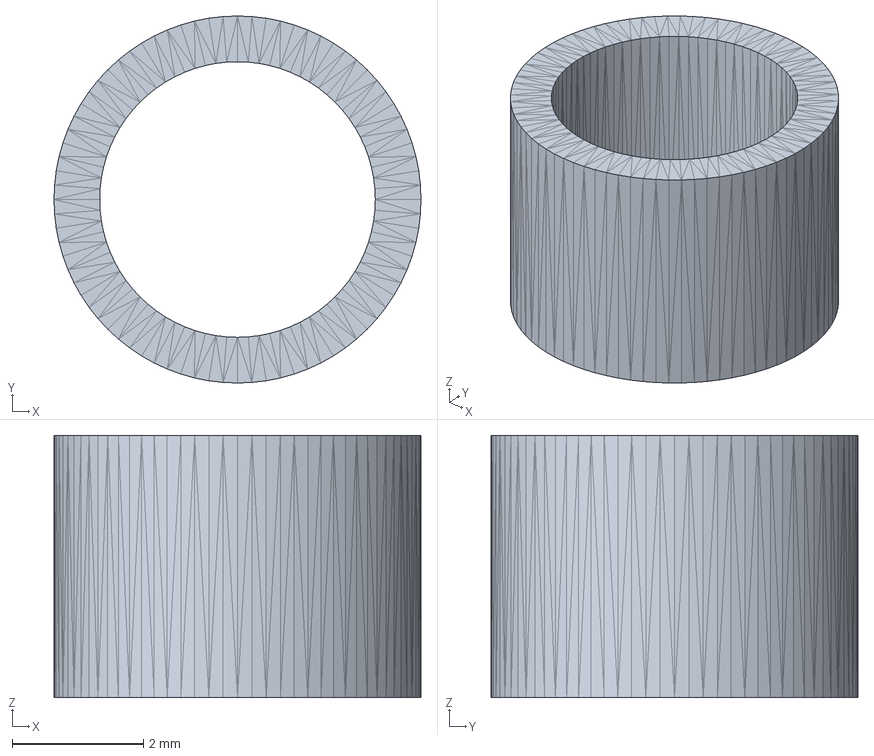
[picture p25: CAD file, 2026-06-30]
SOURCE CAD/INDIVIDUAL STLS/walkie_talkie_PTT_button_insert.step
5.60 x 5.60 x 4.00 mm

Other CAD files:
CUSTOM PCB FABRICATION/SOURCE KICAD/.easyeda_cache/617b05f9bba7410b96c001093d8189e4.step
SOURCE CAD/INDIVIDUAL STLS/walkie_talkie_top_cover.stl
CUSTOM PCB FABRICATION/SOURCE KICAD/.easyeda_cache/10d570588d4c4ccca30b4bf25476f535.step
CUSTOM PCB FABRICATION/SOURCE KICAD/.easyeda_cache/ea3d09bd0a8e416194da70a34a37168f.step
CUSTOM PCB FABRICATION/SOURCE KICAD/.easyeda_cache/07126628bc464d5389bb996c52812f54.obj
CUSTOM PCB FABRICATION/SOURCE KICAD/.easyeda_cache/07126628bc464d5389bb996c52812f54.step
CUSTOM PCB FABRICATION/SOURCE KICAD/.easyeda_cache/10d570588d4c4ccca30b4bf25476f535.obj
CUSTOM PCB FABRICATION/SOURCE KICAD/.easyeda_cache/12c631ea46604e478703d8e42e76d1d7.obj
CUSTOM PCB FABRICATION/SOURCE KICAD/.easyeda_cache/229b69761e2c45dba6a83d8866dec72d.obj
CUSTOM PCB FABRICATION/SOURCE KICAD/.easyeda_cache/2e35dca8e7854ed683469f8d54d1ef17.obj
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

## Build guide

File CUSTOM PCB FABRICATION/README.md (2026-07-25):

# Custom PCB Fabrication

This is a KiCad PCB for those looking to make the walkie talkie from PCBs. Note that you will still have to solder some components.

## PCB Preview

Main board:

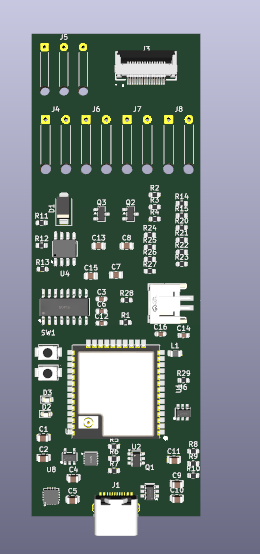
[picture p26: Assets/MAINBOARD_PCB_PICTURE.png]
Main board PCB preview


Front/user-interface board:

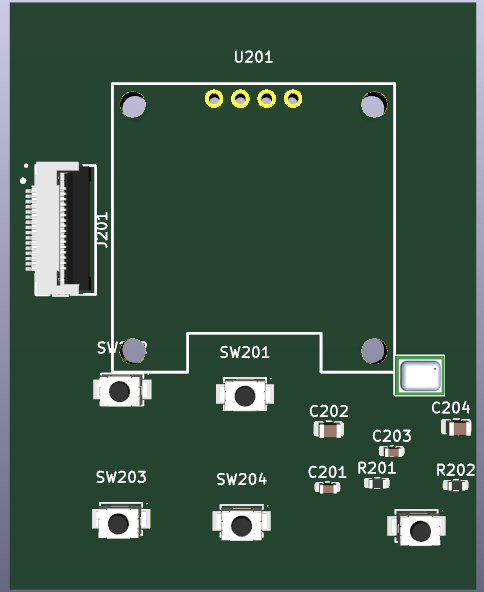
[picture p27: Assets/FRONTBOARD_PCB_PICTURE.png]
Front board PCB preview


## Risks

Although this custom PCB works, I will be manufactering a redesigned much cleaner version later that avoids the hassle of 2 PCB boards and does everything one one, with a much slimmer walkie talkie design.

## Manufacturer Files

In this folder are the source kicad files for the PCB and manufacterable GERBER files.

### Main PCB

- [Gerber/drill ZIP](MANUFACTOR%20FILES/MAIN%20PCB/WalkieTalkie_Main_Gerbers_Drill.zip)
- [JLCPCB BOM CSV](MANUFACTOR%20FILES/MAIN%20PCB/WalkieTalkie_Main_JLCPCB_BOM.csv)
- [JLCPCB CPL / position CSV](MANUFACTOR%20FILES/MAIN%20PCB/WalkieTalkie_Main_JLCPCB_CPL.csv)

### Front PCB

- [Gerber/drill ZIP](MANUFACTOR%20FILES/FRONT%20PCB/WalkieTalkie_Front_Gerbers_Drill.zip)
- [JLCPCB BOM CSV](MANUFACTOR%20FILES/FRONT%20PCB/WalkieTalkie_Front_JLCPCB_BOM.csv)
- [JLCPCB CPL / position CSV](MANUFACTOR%20FILES/FRONT%20PCB/WalkieTalkie_Front_JLCPCB_CPL.csv)

## Parts JLCPCB Can Usually Assemble

Most of the parts and SMD components should be assembled by JLBPCB but you will need to solder these parts:

- PTT Button
- Laser module
- 10K volume potentiometer
- OLED display
- Slim 3W speaker
- Battery
- Power switch

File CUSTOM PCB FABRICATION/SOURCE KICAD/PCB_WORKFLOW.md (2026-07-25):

# Converting the two schematics into PCBs

Create a fresh PCB for each schematic. Do not reuse the archived breakout-board
layouts because their footprints and power architecture are different.

## Main board

1. Open `WalkieTalkie.kicad_pro`, then open `WalkieTalkie.kicad_sch`.
2. Run **Inspect > Electrical Rules Checker**. The imported EasyEDA symbols use
   `Unspecified` pin types, so KiCad reports `pin_to_pin` warnings. Check for
   actual red errors rather than automatically excluding everything.
3. Open **Tools > Assign Footprints**. Confirm every project-library footprint
   resolves through `WalkieTalkie_JLCPCB.pretty`.
4. Select **Tools > Update PCB from Schematic** or press **F8**.
5. When KiCad asks for a board, create and save a new
   `WalkieTalkie_Main.kicad_pcb`.
6. Draw the measured casing outline on `Edge.Cuts`. Add mounting holes, USB-C
   opening, U.FL access, battery clearance and cable-clearance areas before
   placing electrical parts.
7. Place the mechanical parts first: USB-C, ESP32/U.FL edge, battery connector,
   FFC connector and J4-J8 solder pads. Then place regulators and decoupling
   parts tightly around their ICs.

## Front board

1. Open `WalkieTalkie_Front.kicad_pro`, then
   `WalkieTalkie_Front.kicad_sch`.
2. Press **F8** and save a new `WalkieTalkie_Front.kicad_pcb`.
3. Draw the front-board outline from the casing.
4. Enter the exact button-center coordinates, OLED viewing-window location and
   microphone opening before placing the remaining parts.
5. Put a board cutout/acoustic hole directly under the INMP441 port. Verify the
   imported microphone footprint and its pin-1 orientation against the current
   datasheet.

## Routing rules

- Prefer four layers: front signals/components, solid ground, power, rear
  signals/components.
- Route USB D+/D- as a short, length-matched 90-ohm differential pair. Use the
  impedance dimensions supplied by the PCB manufacturer.
- Keep TPS63031 input/output capacitors and inductor beside U7. Minimize both
  switching-current loops.
- Route battery, VSYS and speaker paths with wide copper. Neither MAX98357A
  speaker output is ground.
- Use a solid ground plane beneath the ESP32 module, but keep antenna coax and
  the external antenna away from switching and speaker-current paths.
- Put thermal/ground vias in the TP4056, TPS63031 and MAX98357A exposed pads as
  required by their datasheets.
- Keep I2S traces short and referenced to continuous ground.

## Final checks and JLCPCB files

1. Run **Inspect > Design Rules Checker** until there are no shorts, clearance
   errors, unconnected nets or invalid board-edge errors.
2. Inspect both boards in the 3D Viewer. Confirm connector direction, FFC
   contact side, OLED orientation, button height and enclosure clearances.
3. Generate Gerbers and drill files from **File > Fabrication Outputs**.
4. Generate the component position file for both boards. JLCPCB usually expects
   reference, X, Y, layer and rotation fields.
5. Export a BOM containing the schematic `LCSC` field. Use
   `JLCPCB_ASSEMBLY_PARTS.csv` as the selected-part reference.
6. Recheck JLCPCB stock before ordering. The OLED and INMP441 may require
   Standard PCBA, pre-ordering or a manually sourced substitute.

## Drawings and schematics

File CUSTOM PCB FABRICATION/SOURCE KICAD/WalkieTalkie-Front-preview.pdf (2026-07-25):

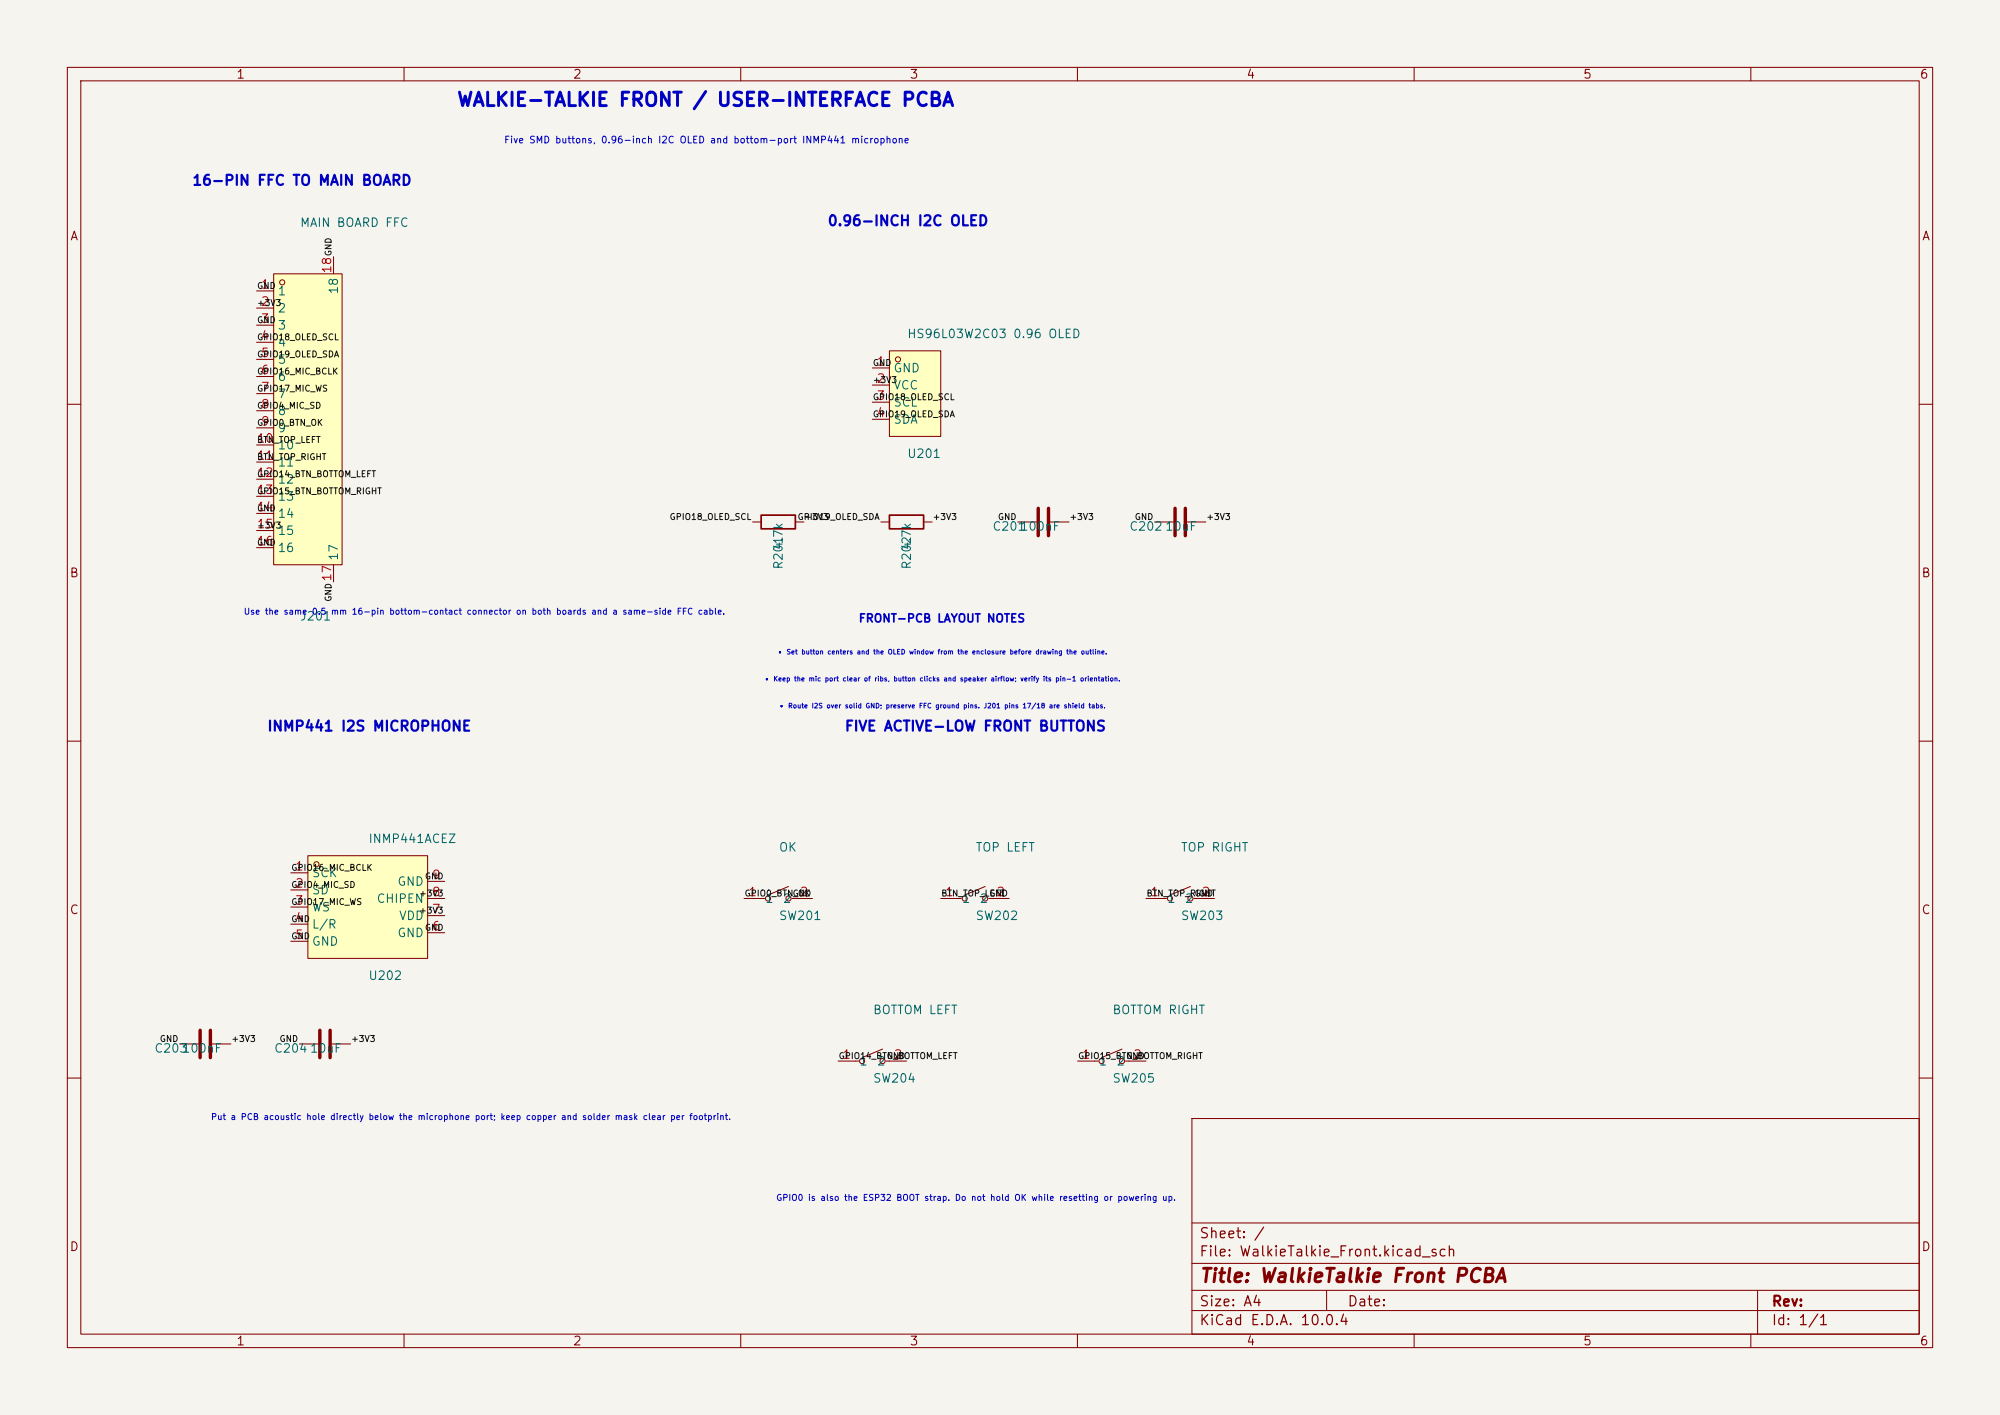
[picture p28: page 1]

16-PIN FFC TO MAIN BOARD

• Route I2S over solid GND; preserve FFC ground pins. J201 pins 17/18 are shield tabs. FIVE ACTIVE-LOW FRONT BUTTONS

Put a PCB acoustic hole directly below the microphone port; keep copper and solder mask clear per footprint.

GPIO0 is also the ESP32 BOOT strap. Do not hold OK while resetting or powering up.

Sheet: /
File: WalkieTalkie_Front.kicad_sch
Title: WalkieTalkie Front PCBA

Size: A4 | Rev:
KiCad E.D.A. 10.0.4 | Id: 1/1

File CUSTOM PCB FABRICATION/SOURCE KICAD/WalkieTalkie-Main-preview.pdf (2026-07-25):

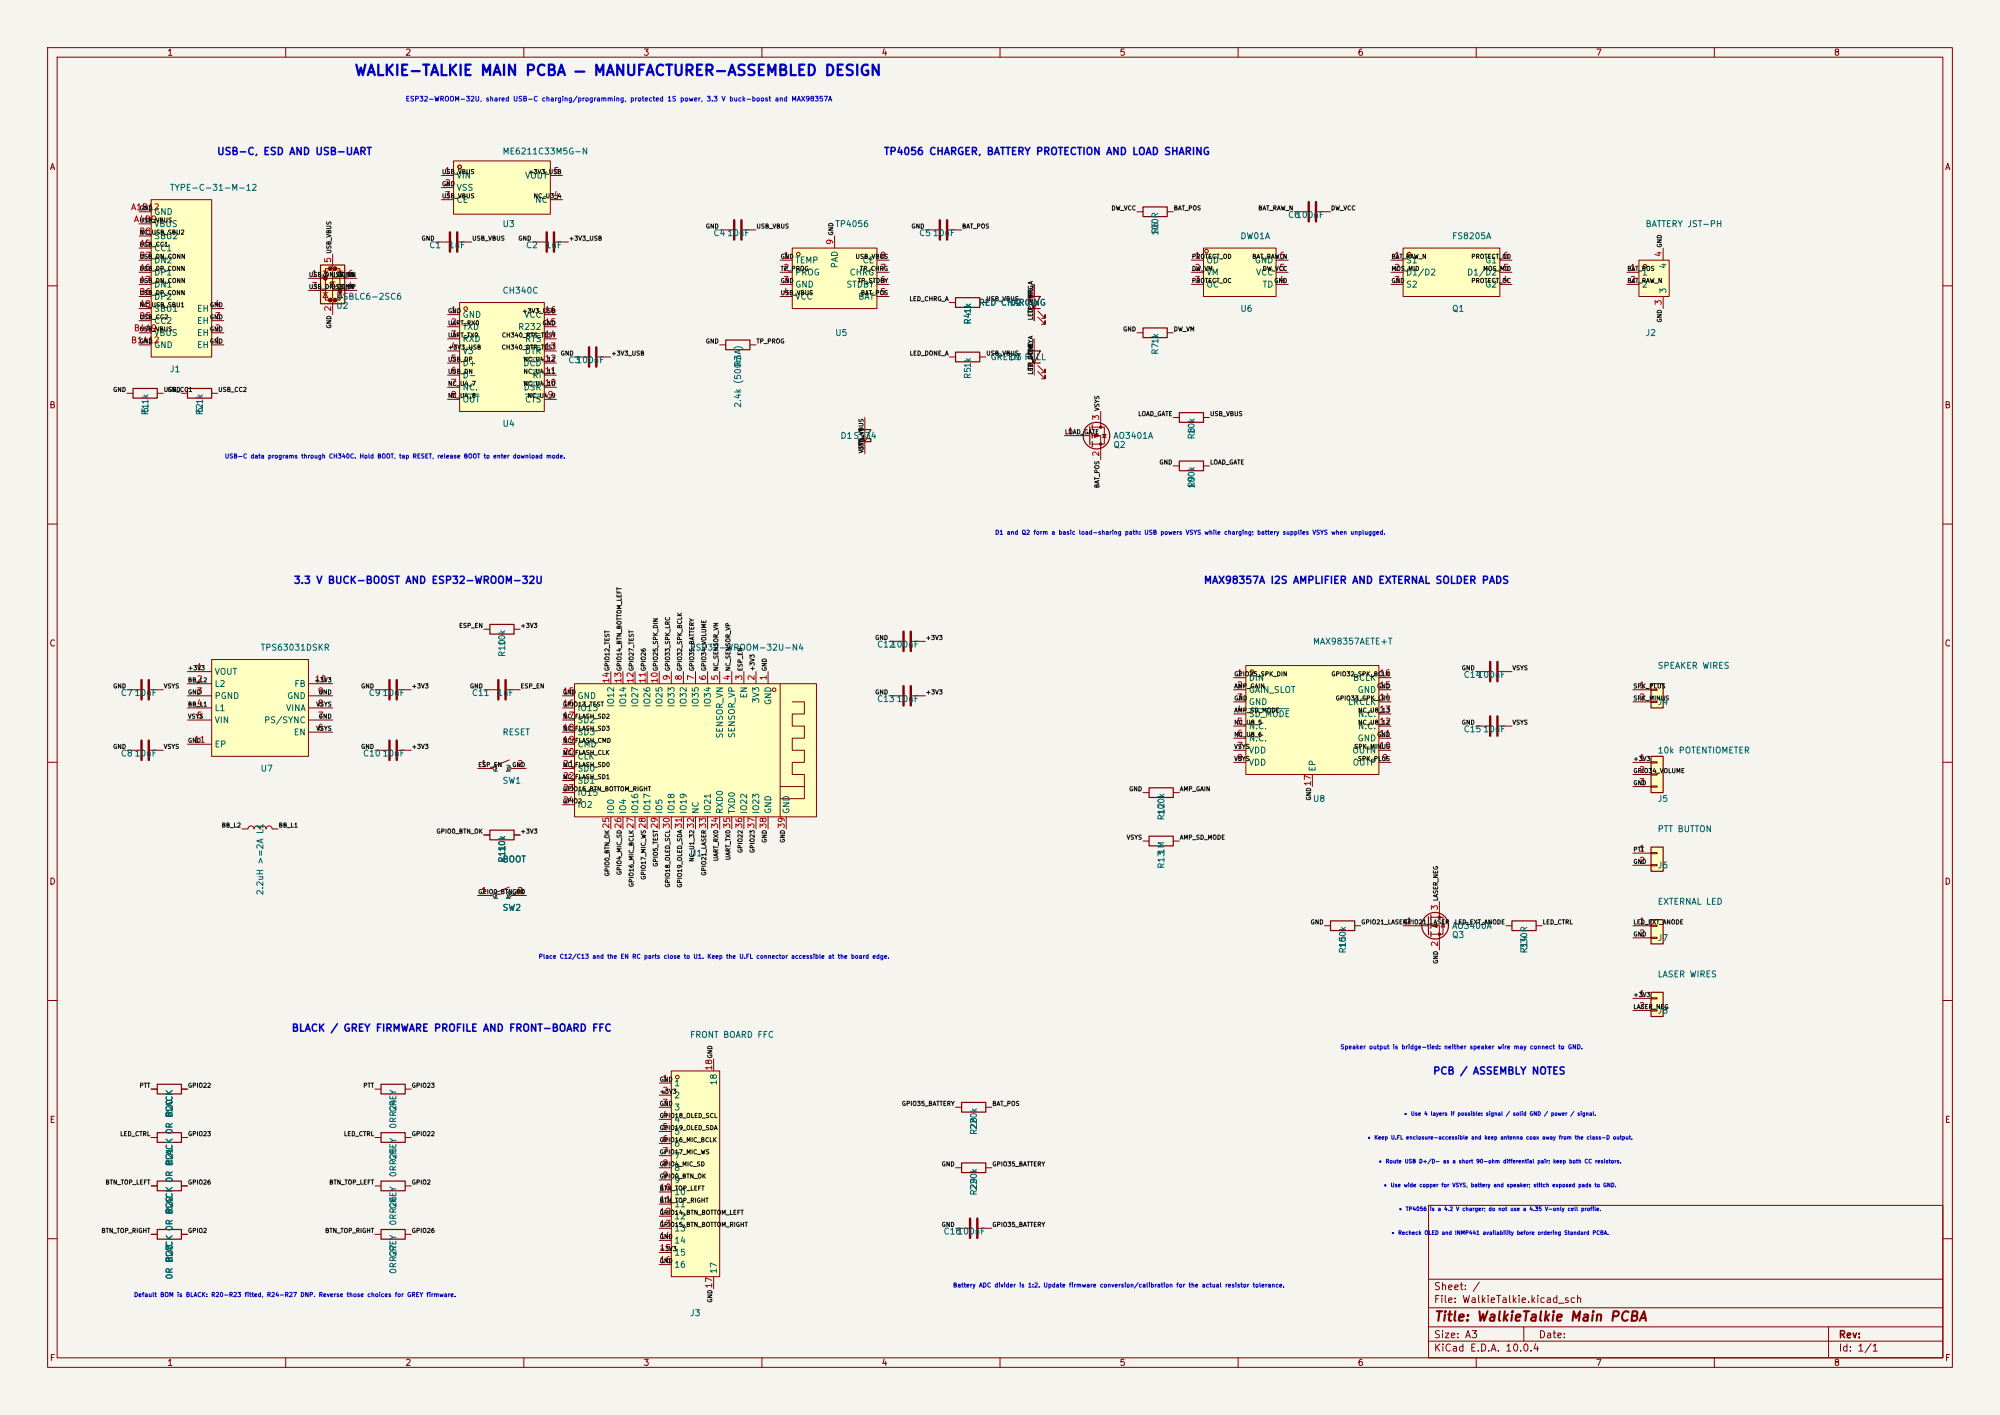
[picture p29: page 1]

ESP32-WROOM-32U, shared USB-C charging/programming, protected 1S power, 3.3 V buck-boost and MAX98357A WALKIE-TALKIE MAIN PCBA — MANUFACTURER-ASSEMBLED DESIGN

TP4056 CHARGER, BATTERY PROTECTION AND LOAD SHARING

USB-C data programs through CH340C. Hold BOOT, tap RESET, release BOOT to enter download mode.

D1 and Q2 form a basic load-sharing path: USB powers VSYS while charging; battery supplies VSYS when unplugged.

3.3 V BUCK-BOOST AND ESP32-WROOM-32U

• Route USB D+/D- as a short 90-ohm differential pair; keep both CC resistors. • Use wide copper for VSYS, battery and speaker; stitch exposed pads to GND. Speaker output is bridge-tied: neither speaker wire may connect to GND. MAX98357A I2S AMPLIFIER AND EXTERNAL SOLDER PADS

2 R20 0R BLACK R23 0R BLACK R22 0R BLACK R21 0R BLACK

• Keep U.FL enclosure-accessible and keep antenna coax away from the class-D output.

• Recheck OLED and INMP441 availability before ordering Standard PCBA.

Default BOM is BLACK: R20-R23 fitted, R24-R27 DNP. Reverse those choices for GREY firmware.

File: WalkieTalkie.kicad_sch
Title: WalkieTalkie Main PCBA

Size: A3 | Rev:
KiCad E.D.A. 10.0.4 | Id: 1/1 | F Date:

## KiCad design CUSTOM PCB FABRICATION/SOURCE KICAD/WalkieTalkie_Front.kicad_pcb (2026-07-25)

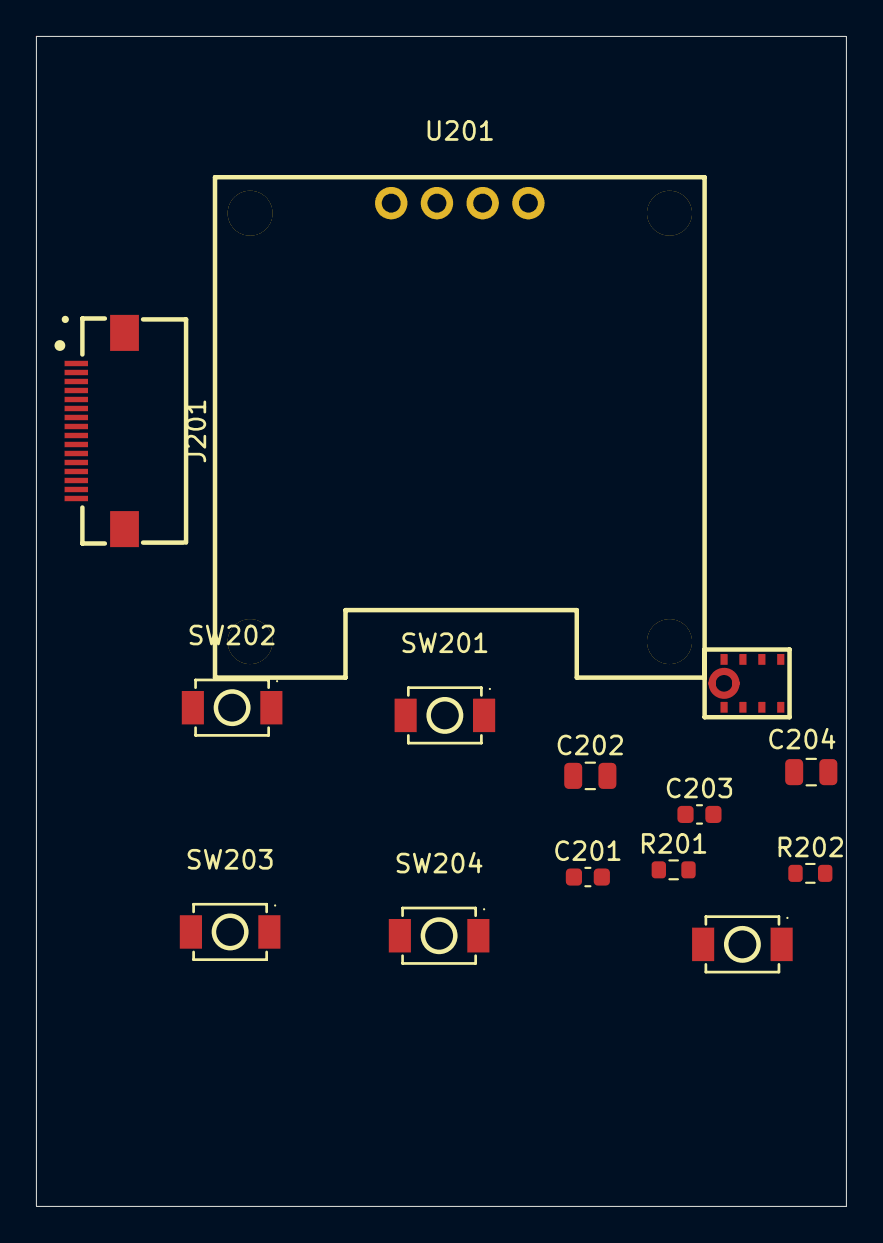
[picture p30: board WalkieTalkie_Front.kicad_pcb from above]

Board: 2 copper layers, 45.0 x 65.0 mm, 14 parts (0 on the bottom side), 12 nets, no tracks yet.

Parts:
C201, C203: 100nF; C_0603_1608Metric
C202, C204: 10uF; C_0805_2012Metric
J201: MAIN BOARD FFC; FPC-SMD_P0.50-16P_FGS-XJ-H2.0
R201, R202: 4.7k; R_0603_1608Metric
SW201: OK; SW-SMD_L3.9-W3.0-P4.45
SW202: TOP LEFT; SW-SMD_L3.9-W3.0-P4.45
SW203: TOP RIGHT; SW-SMD_L3.9-W3.0-P4.45
SW204: BOTTOM LEFT; SW-SMD_L3.9-W3.0-P4.45
SW205: BOTTOM RIGHT; SW-SMD_L3.9-W3.0-P4.45
U201: HS96L03W2C03 0.96 OLED; OLED-TH_L27.8-W27.2-P2.54_C9900033791
U202: INMP441ACEZ; MID-SMD_L4.7-W3.8_INMP441ACEZ

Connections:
/+3V3: C201.2, C202.2, C203.2, C204.2, J201.2, J201.15, R201.2, R202.2, U201.2 (VCC), U202.7 (VDD), U202.8 (CHIPEN)
/BTN_TOP_LEFT: J201.10, SW202.1
/BTN_TOP_RIGHT: J201.11, SW203.1
/GND: C201.1, C202.1, C203.1, C204.1, J201.1, J201.3, J201.14, J201.16, J201.17, J201.18, SW201.2, SW202.2, SW203.2, SW204.2, SW205.2, U201.1 (GND), U202.4 (L/R), U202.5 (GND), U202.6 (GND), U202.9 (GND)
/GPIO0_BTN_OK: J201.9, SW201.1
/GPIO4_MIC_SD: J201.8, U202.2 (SD)
/GPIO14_BTN_BOTTOM_LEFT: J201.12, SW204.1
/GPIO15_BTN_BOTTOM_RIGHT: J201.13, SW205.1
/GPIO16_MIC_BCLK: J201.6, U202.1 (SCK)
/GPIO17_MIC_WS: J201.7, U202.3 (WS)
/GPIO18_OLED_SCL: J201.4, R201.1, U201.3 (SCL)
/GPIO19_OLED_SDA: J201.5, R202.1, U201.4 (SDA)

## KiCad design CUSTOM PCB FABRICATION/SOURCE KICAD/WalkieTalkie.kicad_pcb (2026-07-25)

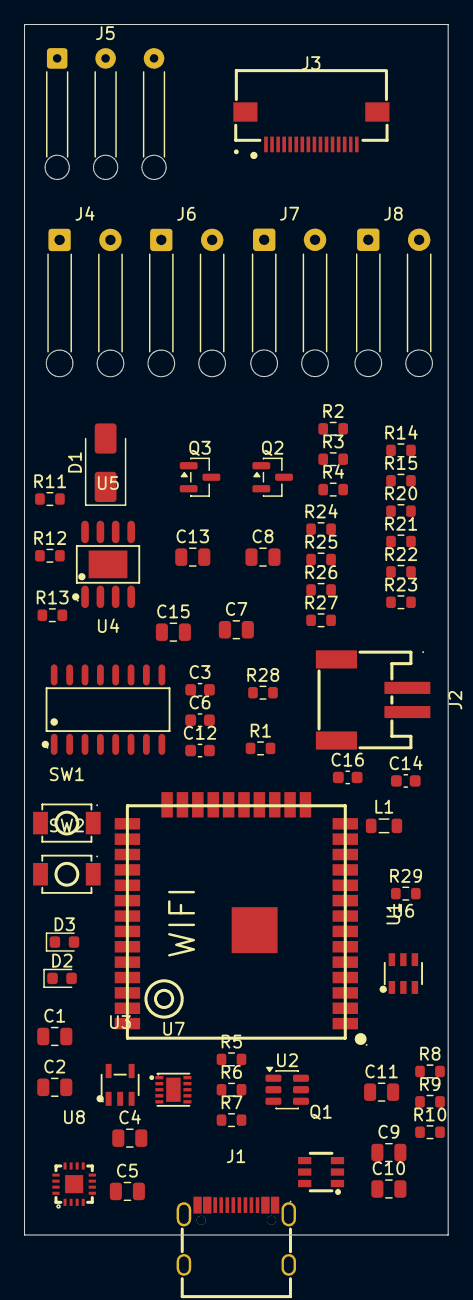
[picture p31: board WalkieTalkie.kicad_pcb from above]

Board: 2 copper layers, 35.0 x 100.0 mm, 66 parts (0 on the bottom side), 57 nets, no tracks yet.

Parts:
C1, C2, C11: 1uF; C_0805_2012Metric
C3, C6, C12, C14, C16: 100nF; C_0603_1608Metric
C4, C5, C7, C8, C9, C10, C13, C15: 10uF; C_0805_2012Metric
D1: SS34; D_SMA
D2: RED CHARGING; LED_0603_1608Metric
D3: GREEN FULL; LED_0603_1608Metric
J1: TYPE-C-31-M-12; USB-C_SMD-TYPE-C-31-M-12_1
J2: BATTERY JST-PH; CONN-SMD_P2.00_S2B-PH-SM4-TB-LF-SN
J3: FRONT BOARD FFC; FPC-SMD_P0.50-16P_FGS-XJ-H2.0
J4: SPEAKER WIRES; SolderWire-0.25sqmm_1x02_P4.2mm_D0.65mm_OD1.7mm_Relief
J5: 10k POTENTIOMETER; SolderWire-0.15sqmm_1x03_P4mm_D0.5mm_OD1.5mm_Relief
J6: PTT BUTTON; SolderWire-0.25sqmm_1x02_P4.2mm_D0.65mm_OD1.7mm_Relief
J7: EXTERNAL LED; SolderWire-0.25sqmm_1x02_P4.2mm_D0.65mm_OD1.7mm_Relief
J8: LASER WIRES; SolderWire-0.25sqmm_1x02_P4.2mm_D0.65mm_OD1.7mm_Relief
L1: 2.2uH >=2A; L_0805_2012Metric
Q1: FS8205A; SOT-23-6_L2.9-W1.6-P0.95-LS2.8-BR
Q2: AO3401A; SOT-23
Q3: AO3400A; SOT-23
R1, R2: 5.1k; R_0603_1608Metric
R3: 2.4k (500mA); R_0603_1608Metric
R4, R5, R7: 1k; R_0603_1608Metric
R6: 100R; R_0603_1608Metric
R8, R10, R11: 10k; R_0603_1608Metric
R9, R12, R15: 100k; R_0603_1608Metric
R13: 1M; R_0603_1608Metric
R14: 330R; R_0603_1608Metric
R20, R21, R22, R23: 0R BLACK; R_0603_1608Metric
R24, R25, R26, R27: 0R GREY; R_0603_1608Metric
R28, R29: 220k; R_0603_1608Metric
SW1: RESET; SW-SMD_L3.9-W3.0-P4.45
SW2: BOOT; SW-SMD_L3.9-W3.0-P4.45
U1: ESP32-WROOM-32U-N4; WIFIM-SMD_38P-L19.2-W18.0-P1.27
U2: USBLC6-2SC6; SOT-23-6
U3: ME6211C33M5G-N; SOT-23-5_L3.0-W1.7-P0.95-LS2.8-BL
U4: CH340C; SOP-16_L10.0-W3.9-P1.27-LS6.0-BL
U5: TP4056; ESOP-8_L4.9-W3.9-P1.27-LS6.0-BL-EP-4
U6: DW01A; SOT-23-6_L2.9-W1.6-P0.95-LS2.8-BL
U7: TPS63031DSKR; SON-10_L2.5-W2.5-P0.50-TL-EP
U8: MAX98357AETE+T; TQFN-16_L3.0-W3.0-P0.50-BL-EP1.5

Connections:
/+3V3: C9.2, C10.2, C12.2, C13.2, J3.2, J3.15, J5.1, J8.1, R10.2, R11.2, U1.2 (3V3), U7.1 (VOUT), U7.10 (FB)
/+3V3_USB: C2.2, C3.2, U3.5 (VOUT), U4.4 (V3), U4.16 (VCC)
/AMP_GAIN: R12.2, U8.2 (GAIN_SLOT)
/AMP_SD_MODE: R13.2, U8.4 (~SD_MODE)
/BAT_POS: C5.2, J2.1, Q2.2 (S), R6.2, R28.2, U5.5 (BAT)
/BAT_RAW_N: C6.1, J2.2, Q1.1 (S1), U6.6 (GND)
/BB_L1: L1.2, U7.4 (L1)
/BB_L2: L1.1, U7.2 (L2)
/BTN_TOP_LEFT: J3.10, R22.1, R26.1
/BTN_TOP_RIGHT: J3.11, R23.1, R27.1
/DW_VCC: C6.2, R6.1, U6.5 (VCC)
/DW_VM: R7.2, U6.2 (VM)
/ESP_EN: C11.2, R10.1, SW1.1, U1.3 (EN)
/GND: C1.1, C2.1, C3.1, C4.1, C5.1, C7.1, C8.1, C9.1, C10.1, C11.1, C12.1, C13.1, C14.1, C15.1, C16.1, J1.1 (EH), J1.2 (EH), J1.3 (EH), J1.4 (EH), J1.A1B12 (GND), J1.B1A12 (GND), J2.3, J2.4, J3.1, J3.3, J3.14, J3.16, J3.17, J3.18, J5.3, J6.2, J7.2, Q1.3 (S2), Q3.2 (S), R1.1, R2.1, R3.1, R7.1, R9.1, R12.1, R15.1, R29.1, SW1.2, SW2.2, U1.1 (GND), U1.15 (GND), U1.38 (GND), U1.39 (GND), U2.2 (GND), U3.2 (VSS), U4.1 (GND), U4.15 (R232), U5.1 (TEMP), U5.3 (GND), U5.9 (PAD), U6.4 (TD), U7.3 (PGND), U7.7 (PS/SYNC), U7.9 (GND), U7.11 (EP), U8.3 (GND), U8.11 (GND), U8.15 (GND), U8.17 (EP)
/GPIO0_BTN_OK: J3.9, R11.1, SW2.1, U1.25 (IO0)
/GPIO2: R23.2, R26.2, U1.24 (IO2)
/GPIO4_MIC_SD: J3.8, U1.26 (IO4)
/GPIO14_BTN_BOTTOM_LEFT: J3.12, U1.13 (IO14)
/GPIO15_BTN_BOTTOM_RIGHT: J3.13, U1.23 (IO15)
/GPIO16_MIC_BCLK: J3.6, U1.27 (IO16)
/GPIO17_MIC_WS: J3.7, U1.28 (IO17)
/GPIO18_OLED_SCL: J3.4, U1.30 (IO18)
/GPIO19_OLED_SDA: J3.5, U1.31 (IO19)
/GPIO21_LASER: Q3.1 (G), R15.2, U1.33 (IO21)
/GPIO22: R20.2, R25.2, U1.36 (IO22)
/GPIO23: R21.2, R24.2, U1.37 (IO23)
/GPIO25_SPK_DIN: U1.10 (IO25), U8.1 (DIN)
/GPIO26: R22.2, R27.2, U1.11 (IO26)
/GPIO32_SPK_BCLK: U1.8 (IO32), U8.16 (BCLK)
/GPIO33_SPK_LRC: U1.9 (IO33), U8.14 (LRCLK)
/GPIO34_VOLUME: J5.2, U1.6 (IO34)
/GPIO35_BATTERY: C16.2, R28.1, R29.2, U1.7 (IO35)
/LASER_NEG: J8.2, Q3.3 (D)
/LED_CHRG_A: D2.1 (K), R4.1
/LED_CTRL: R14.2, R21.1, R25.1
/LED_DONE_A: D3.1 (K), R5.1
/LED_EXT_ANODE: J7.1, R14.1
/LOAD_GATE: Q2.1 (G), R8.1, R9.2
/MOS_MID: Q1.2 (D1/D2), Q1.5 (D1/D2)
/PROTECT_OC: Q1.4 (G2), U6.3 (OC)
/PROTECT_OD: Q1.6 (G1), U6.1 (OD)
/PTT: J6.1, R20.1, R24.1
/SPK_MINUS: J4.2, U8.10 (OUTN)
/SPK_PLUS: J4.1, U8.9 (OUTP)
/TP_CHRG: D2.2 (A), U5.7 (CHRG)
/TP_PROG: R3.2, U5.2 (PROG)
/TP_STDBY: D3.2 (A), U5.6 (STDBY)
/UART_RX0: U1.34 (RXD0), U4.2 (TXD)
/UART_TX0: U1.35 (TXD0), U4.3 (RXD)
/USB_CC1: J1.A5 (CC1), R1.2
/USB_CC2: J1.B5 (CC2), R2.2
/USB_DN: U2.6 (I/O1), U4.6 (D-)
/USB_DN_CONN: J1.A7 (DN1), J1.B7 (DN2), U2.1 (I/O1)
/USB_DP: U2.4 (I/O2), U4.5 (D+)
/USB_DP_CONN: J1.A6 (DP1), J1.B6 (DP2), U2.3 (I/O2)
/USB_VBUS: C1.2, C4.2, D1.2 (A), J1.A4B9 (VBUS), J1.B4A9 (VBUS), R4.2, R5.2, R8.2, U2.5 (VBUS), U3.1 (VIN), U3.3 (CE), U5.4 (VCC), U5.8 (CE)
/VSYS: C7.2, C8.2, C14.2, C15.2, D1.1 (K), Q2.3 (D), R13.1, U7.5 (VIN), U7.6 (EN), U7.8 (VINA), U8.7 (VDD), U8.8 (VDD)

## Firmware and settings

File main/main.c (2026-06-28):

#include <inttypes.h>
#include <stdbool.h>
#include <stdint.h>
#include <stdio.h>
#include <stdlib.h>
#include <string.h>
#include <sys/stat.h>

#include "esp_adc/adc_cali.h"
#include "esp_adc/adc_cali_scheme.h"
#include "esp_adc/adc_oneshot.h"
#include "esp_check.h"
#include "esp_event.h"
#include "esp_heap_caps.h"
#include "esp_image_format.h"
#include "esp_log.h"
#include "esp_mac.h"
#include "esp_netif.h"
#include "esp_now.h"
#include "esp_ota_ops.h"
#include "esp_http_server.h"
#include "esp_spiffs.h"
#include "esp_timer.h"
#include "esp_wifi.h"
#include "freertos/FreeRTOS.h"
#include "freertos/idf_additions.h"
#include "freertos/queue.h"
#include "freertos/semphr.h"
#include "freertos/task.h"
#include "nvs_flash.h"
#include "sdkconfig.h"

#include "walkie_audio.h"
#include "walkie_display.h"
#include "walkie_types.h"

#include "driver/gpio.h"
#include "driver/i2s_common.h"
#include "driver/i2s_std.h"
#include "driver/ledc.h"

/*
 * Firmware map:
 * - Hardware constants and board_config_init() select the black/grey pinout.
 * - control_task() owns buttons, menus, lights, battery/volume smoothing, and OLED redraws.
 * - capture_task() records the I2S mic, cleans/gains/compresses it, then sends ESP-NOW frames.
 * - handle_radio_item() validates packets, updates link quality, and feeds the jitter buffer.
 * - playback_task() drains the jitter buffer to the I2S speaker and fills short packet gaps.
 */

static const char *TAG = "walkie";

/* Shared fixed wiring. The board-specific swaps live in board_config_init(). */
#define OLED_SCL GPIO_NUM_18
#define OLED_SDA GPIO_NUM_19

#define SPK_BCLK GPIO_NUM_32
#define SPK_WS   GPIO_NUM_33
#define SPK_DIN  GPIO_NUM_25

#define MIC_BCLK GPIO_NUM_16
#define MIC_WS   GPIO_NUM_17
#define MIC_SD   GPIO_NUM_4

#define OK_PIN        GPIO_NUM_0
#define BOT_LEFT_PIN  GPIO_NUM_14
#define BOT_RIGHT_PIN GPIO_NUM_15
#define LASER_PIN     GPIO_NUM_21

#define POT_PIN GPIO_NUM_34
#define BAT_PIN GPIO_NUM_35

#define RCAR_LEFT_PWM_PIN  GPIO_NUM_1
#define RCAR_RIGHT_PWM_PIN GPIO_NUM_3

#define LOGICAL_CHANNEL_MIN 1
#define LOGICAL_CHANNEL_MAX 20
#define FLAG_KID 0x01
#define KID_CHANNEL 1

#define SAMPLE_RATE_HZ      16000
#define FRAME_MS            20
#define SAMPLES_PER_FRAME   ((SAMPLE_RATE_HZ * FRAME_MS) / 1000)
#define AUDIO_PAYLOAD_BYTES (SAMPLES_PER_FRAME / 2)
#define RADIO_RX_DATA_MAX   250

#define RX_QUEUE_FRAMES   10
#define RX_PREFILL_FRAMES 4

#define POT_UPDATE_MS   90
#define BATT_UPDATE_MS  700
#define RESOURCE_UPDATE_MS 500
#define OLED_UPDATE_MS  180
#define HEARTBEAT_MS    650
#define LINK_TIMEOUT_MS 2200
#define SCAN_WAIT_MS    95

#define RCAR_AP_SSID "ESP32-Tank"
#define RCAR_WEB_IP_TEXT "192.168.4.1"
#define RCAR_SERVO_FREQ_HZ 50
#define RCAR_LEFT_STOP_US 1500
#define RCAR_RIGHT_STOP_US 1500
#define RCAR_LEFT_FWD_US 2500
#define RCAR_LEFT_REV_US 500
#define RCAR_RIGHT_FWD_US 500
#define RCAR_RIGHT_REV_US 2500
#define RCAR_DEADZONE 6
#define RCAR_BUTTON_SPEED 80
#define RCAR_CMD_SEND_MS 60
#define RCAR_STATUS_SEND_MS 180
#define RCAR_FAILSAFE_MS 650

/* The range telemetry cadence. One line per second is frequent enough to show
 * packet loss trends while keeping serial/flash writes small. */
#define DEBUG_JSON_STATS_MS 1000

/* Onboard range-test log storage. The partition is mounted at /fieldlog and the
 * log is JSON Lines so every record can be parsed independently after a test. */
#define FIELD_LOG_MOUNT_PATH "/fieldlog"
#define FIELD_LOG_CURRENT_PATH FIELD_LOG_MOUNT_PATH "/range.jsonl"
#define FIELD_LOG_PREVIOUS_PATH FIELD_LOG_MOUNT_PATH "/range.prev.jsonl"

/* Keep two files under the 512 KB SPIFFS partition: current plus previous. */
#define FIELD_LOG_MAX_FILE_BYTES (220 * 1024)

/* Flash writes happen from a low-priority task. The control loop only drops a
 * fixed-size line into this short queue so audio timing is not blocked by flash. */
#define FIELD_LOG_QUEUE_DEPTH    8
#define FIELD_LOG_LINE_BYTES     512

/* Range-first ESP-NOW settings. TX power is quarter-dBm; 84 requests the ESP32 max. */
#define WIFI_MAX_TX_POWER_QDBM 84
#define LINK_RSSI_UNKNOWN_DBM (-127)
#define LINK_RSSI_WEAK_DBM    (-92)
#define LINK_RSSI_STRONG_DBM  (-45)

/* Weak-link redundancy threshold. When the RSSI-derived quality is <= 65%, or
 * the peer is not linked yet, each 20 ms audio frame is sent twice. */
#define AUDIO_REDUNDANCY_LINK_QUALITY_PCT 65
#define AUDIO_REDUNDANCY_EXTRA_COPIES     1

#define TX_PREAMBLE_FRAMES 2
#define TX_END_FRAMES      2
#define MIC_WARMUP_FRAMES  2

/* Packet types are intentionally tiny so the 20 ms ADPCM voice frames fit in ESP-NOW. */
#define PKT_AUDIO     0xA1
#define PKT_HEART     0xB1
#define PKT_SCAN_REQ  0xB2
#define PKT_SCAN_RESP 0xB3
#define PKT_RCAR_DRIVE  0xC1
#define PKT_RCAR_STATUS 0xC2
#define PROTO_VERSION 0x02

/**
 * Individual counters included in the once-per-second field-test JSON line.
 *
 * These are intentionally event-style counters rather than logs of every packet.
 * A one-second aggregate is compact enough for flash while still showing whether
 * long-range jitter is caused by packet loss, duplicate recovery, wrong-channel
 * traffic, or local ESP-NOW send failures.
 */
typedef enum {
    DBG_TX_AUDIO = 0,
    DBG_TX_AUDIO_DUP,
    DBG_TX_CTRL,
    DBG_TX_NO_MEM,
    DBG_TX_FAIL,
    DBG_RX_AUDIO,
    DBG_RX_AUDIO_DUP,
    DBG_RX_AUDIO_OLD,
    DBG_RX_PLC,
    DBG_RX_CTRL,
    DBG_RX_WRONG_PEER,
    DBG_RX_BAD_PROTO,
    DBG_RX_WRONG_CHANNEL,
} debug_stat_id_t;

/**
 * Small shared control-packet header.
 *
 * Heartbeat and scan packets use only these fields. Audio packets start with the
 * same first fields so handle_radio_item() can validate type/version/channel
 * before looking at the rest of the payload.
 */
typedef struct __attribute__((packed)) {
    uint8_t type;
    uint8_t version;
    uint8_t logical_channel;
    uint8_t flags;
    uint16_t seq;
} walkie_ctrl_packet_t;

/**
 * One compressed voice frame carried by ESP-NOW.
 *
 * The packet contains one 20 ms ADPCM frame. predictor and step_index capture
 * the encoder state at the start of the frame, letting the receiver decode the
 * packet independently enough to recover after short loss.
 */
typedef struct __attribute__((packed)) {
    uint8_t type;
    uint8_t version;
    uint8_t logical_channel;
    uint8_t flags;
    uint16_t seq;
    int16_t predictor;
    uint8_t step_index;
    uint16_t sample_count;
    uint8_t payload[AUDIO_PAYLOAD_BYTES];
} walkie_audio_packet_t;

/**
 * RC car drive/status packet.
 *
 * In Walkie mode the grey unit sends PKT_RCAR_DRIVE with signed wheel speeds
 * from -100 to +100. The black unit applies those speeds to GPIO1/GPIO3 servo
 * PWM and answers with PKT_RCAR_STATUS so the controller can light its LED and
 * show LINK ON. Web-server mode does not use ESP-NOW; it runs AP + HTTP locally
 * on the black walkie instead.
 */
typedef struct __attribute__((packed)) {
    uint8_t type;
    uint8_t version;
    uint8_t logical_channel;
    uint8_t flags;
    uint16_t seq;
    int8_t left_speed;
    int8_t right_speed;
    uint8_t reserved;
} walkie_rcar_packet_t;

/**
 * Debounce state for one active-low GPIO button.
 */
typedef struct {
    gpio_num_t pin;
    bool state;
    bool last_raw;
    int debounce_ms;
    int64_t last_change_ms;
} debounced_button_t;

/**
 * Queue item copied out of the ESP-NOW receive callback.
 *
 * Includes packet bytes, source MAC, and RSSI metadata. Keeping this separate
 * from protocol structs lets the callback remain generic and lightweight.
 */
typedef struct {
    size_t len;
    int8_t rssi;
    uint8_t src_mac[6];
    uint8_t data[RADIO_RX_DATA_MAX];
} radio_rx_item_t;

/**
 * Small ring buffer between radio receive and speaker playback.
 *
 * ESP-NOW packets do not arrive at a perfectly steady 20 ms cadence. This buffer
 * absorbs timing jitter, tracks sequence history, and stores the last good frame
 * for short packet-loss concealment.
 */
typedef struct {
    SemaphoreHandle_t mutex;
    int16_t frames[RX_QUEUE_FRAMES][SAMPLES_PER_FRAME];
    int16_t last_good[SAMPLES_PER_FRAME];
    int rd;
    int wr;
    int count;
    bool started;
    bool have_last_good;
    bool have_last_seq;
    uint16_t last_seq;
    TickType_t last_rx_tick;
} jitter_buffer_t;

/**
 * Per-second radio counters printed as JSON for long-range field testing.
 *
 * The counters reset after every debug line, so a saved USB serial log can be
 * graphed as "what happened during this second" instead of needing post-
 * processing on lifetime totals.
 */
typedef struct {
    /* Packets this unit tried to send. Duplicates are tracked separately so we
     * can confirm whether weak-link redundancy actually turned on. */
    uint32_t tx_audio;
    uint32_t tx_audio_dup;
    uint32_t tx_ctrl;

    /* ESP-NOW send-side pressure. NO_MEM means the Wi-Fi/ESP-NOW queue was full;
     * tx_fail is for other immediate esp_now_send() errors. */
    uint32_t tx_no_mem;
    uint32_t tx_fail;

    /* Receive-side audio health. rx_audio is accepted unique audio; duplicate
     * and old packets are counted but intentionally not played. */
    uint32_t rx_audio;
    uint32_t rx_audio_dup;
    uint32_t rx_audio_old;

    /* Packet-loss concealment frames generated locally to cover missing audio. */
    uint32_t rx_plc;

    /* Control and reject counters help separate real range loss from wrong peer,
     * wrong protocol, or wrong logical-channel situations. */
    uint32_t rx_ctrl;
    uint32_t rx_wrong_peer;
    uint32_t rx_bad_proto;
    uint32_t rx_wrong_channel;
} radio_debug_stats_t;

/**
 * Fixed-size queue item for field logging.
 *
 * Dynamic allocation in an audio/radio firmware is a tiny gremlin factory, so
 * log records are copied into fixed buffers and sent to the flash task.
 */
typedef struct {
    char line[FIELD_LOG_LINE_BYTES];
} field_log_line_t;

/**
 * Mutable application state protected by s_state_lock.
 *
 * Tasks share this struct for UI mode, button levels, logical channel, battery,
 * link status, and derived settings. Rendering code never reads it directly; it
 * receives a walkie_ui_snapshot_t copy instead.
 */
typedef struct {
    walkie_ui_mode_t ui_mode;
    int selected_app;
    int current_channel;
    bool laser_on;

    bool tl_down;
    bool tr_down;
    bool ok_down;
    bool bl_down;
    bool br_down;
    bool ptt_down;

    int base_vol_percent;
    float vbat;
    int batt_pct;

    TickType_t last_link_tick;
    int link_rssi_dbm;
    int link_quality_pct;
    TickType_t last_heart_tick;
    TickType_t last_pot_tick;
    TickType_t last_batt_tick;
    TickType_t last_oled_tick;
    TickType_t last_stats_tick;
    int64_t kid_hold_start_ms;
    int64_t rx_led_until_ms;

    walkie_extra_state_t extra;
} walkie_app_state_t;

static walkie_board_config_t s_board;
static walkie_display_t s_display;

static SemaphoreHandle_t s_state_lock;
static walkie_app_state_t s_app;
static jitter_buffer_t s_jitter;

static QueueHandle_t s_radio_rx_queue;

static i2s_chan_handle_t s_i2s_tx;
static i2s_chan_handle_t s_i2s_rx;
static adc_oneshot_unit_handle_t s_adc_unit;
static adc_channel_t s_pot_channel;
static adc_channel_t s_bat_channel;
static adc_cali_handle_t s_bat_cali;
static bool s_bat_cali_ok;
static bool s_adc_ready;
static bool s_radio_ready;
static bool s_i2s_tx_ready;
static bool s_i2s_rx_ready;
static bool s_wifi_initialized;

/* RC car runtime objects. The web server exists only while black-unit Web mode
 * is active. Servo PWM is initialized lazily so GPIO1/GPIO3 remain available for
 * normal UART flashing/logging unless the RC app is actually using them. */
static httpd_handle_t s_rcar_httpd;
static esp_netif_t *s_rcar_ap_netif;
static bool s_rcar_pwm_ready;
static uint16_t s_rcar_tx_seq;
static TickType_t s_rcar_last_cmd_tick;
static TickType_t s_rcar_last_status_tick;
static int s_rcar_last_sent_left;
static int s_rcar_last_sent_right;

/* Debug counters can be touched from several tasks, so they use a tiny spinlock
 * instead of the larger app-state mutex. They are quick increment-only paths. */
static portMUX_TYPE s_debug_stats_mux = portMUX_INITIALIZER_UNLOCKED;
static radio_debug_stats_t s_debug_stats;

/* Flash logging is optional at runtime. If SPIFFS fails to mount, the firmware
 * still runs normally and keeps serial JSON output. */
static QueueHandle_t s_field_log_queue;
static bool s_field_log_ready;

static debounced_button_t s_ok_btn;
static debounced_button_t s_left_btn;
static debounced_button_t s_right_btn;
static debounced_button_t s_bl_btn;
static debounced_button_t s_br_btn;

_Static_assert(sizeof(walkie_audio_packet_t) <= RADIO_RX_DATA_MAX, "radio rx buffer too small");
_Static_assert(sizeof(walkie_rcar_packet_t) <= RADIO_RX_DATA_MAX, "rcar packet too large");

/**
 * Initialize one debounced, active-low button.
 *
 * The physical buttons are wired to pull the GPIO low when pressed. This stores
 * the current raw level and timestamp so button_pressed() can later reject
 * bounce/noise before reporting a real edge.
 */
static void button_init(debounced_button_t *button, gpio_num_t pin, int debounce_ms)
{
    button->pin = pin;
    button->debounce_ms = debounce_ms;
    button->state = gpio_get_level(pin);
    button->last_raw = button->state;
    button->last_change_ms = esp_timer_get_time() / 1000;
}

/**
 * Return true exactly once when a debounced press edge is observed.
 *
 * This is edge-based, not level-based: holding the button down does not keep
 * returning true. Long-hold behavior is implemented separately by checking
 * button_down() over time.
 */
static bool button_pressed(debounced_button_t *button, int64_t now_ms)
{
    bool raw = gpio_get_level(button->pin);
    if (raw != button->last_raw) {
        button->last_raw = raw;
        button->last_change_ms = now_ms;
        return false;
    }

    if (raw != button->state && (now_ms - button->last_change_ms) >= button->debounce_ms) {
        button->state = raw;
        return button->state == 0;
    }

    return false;
}

/**
 * Return the current debounced button level as a pressed/not-pressed boolean.
 *
 * Used for UI indicators and hold detection, where we need to know that a
 * button is currently down rather than just seeing the first press edge.
 */
static bool button_down(const debounced_button_t *button)
{
    return button->state == 0;
}

/**
 * Parse a colon-separated MAC address from Kconfig.
 *
 * If the string is malformed the caller keeps its compiled-in default MAC.
 * This lets the firmware be configured per pair without editing C source.
 */
static bool parse_mac_string(const char *text, uint8_t mac[6])
{
    unsigned int bytes[6];
    if (sscanf(text, "%2x:%2x:%2x:%2x:%2x:%2x",
               &bytes[0], &bytes[1], &bytes[2], &bytes[3], &bytes[4], &bytes[5]) != 6) {
        return false;
    }
    for (int i = 0; i < 6; ++i) {
        mac[i] = (uint8_t)bytes[i];
    }
    return true;
}

/**
 * Format a MAC address into a caller-provided text buffer.
 *
 * Used only for boot logs so the flashed image can confirm whether it is the
 * black or grey unit and which peer it expects to talk to.
 */
static const char *mac_to_str(const uint8_t mac[6], char *buffer, size_t buffer_len)
{
    snprintf(buffer, buffer_len, "%02X:%02X:%02X:%02X:%02X:%02X",
             mac[0], mac[1], mac[2], mac[3], mac[4], mac[5]);
    return buffer;
}

/**
 * Fill the board profile selected by sdkconfig.
 *
 * This is the central place for physical differences between the black and grey
 * walkies: GPIO swaps, battery divider smoothing, peer MAC, and per-unit mic
 * gain calibration. The rest of the code reads s_board and stays board-agnostic.
 */
static void board_config_init(walkie_board_config_t *board)
{
    uint8_t black_mac[6] = {0xA4, 0xF0, 0x0F, 0x66, 0xD2, 0xD0};
    uint8_t grey_mac[6]  = {0xA4, 0xF0, 0x0F, 0x67, 0xBA, 0x1C};

    parse_mac_string(CONFIG_WALKIE_BLACK_MAC, black_mac);
    parse_mac_string(CONFIG_WALKIE_GREY_MAC, grey_mac);

#if CONFIG_WALKIE_BOARD_BLACK
    board->label = "BLACK";
    memcpy(board->self_mac, black_mac, sizeof(board->self_mac));
    memcpy(board->peer_mac, grey_mac, sizeof(board->peer_mac));
    board->ptt_pin = GPIO_NUM_22;
    board->led_pin = GPIO_NUM_23;
    board->top_left_pin = GPIO_NUM_26;
    board->top_right_pin = GPIO_NUM_2;
    board->batt_r_top = 100000.0f;
    board->batt_r_bottom = 100000.0f;
    board->batt_avg_samples = 8;
    board->batt_smooth_alpha = 0.12f;
    board->mic_base_gain_q10 = 4096;
    board->mic_boost_gain_q10 = 8192;
    board->mic_cut_gain_q10 = 2048;
#else
    board->label = "GREY";
    memcpy(board->self_mac, grey_mac, sizeof(board->self_mac));
    memcpy(board->peer_mac, black_mac, sizeof(board->peer_mac));
    board->ptt_pin = GPIO_NUM_23;
    board->led_pin = GPIO_NUM_22;
    board->top_left_pin = GPIO_NUM_2;
    board->top_right_pin = GPIO_NUM_26;
    board->batt_r_top = 220000.0f;
    board->batt_r_bottom = 220000.0f;
    board->batt_avg_samples = 16;
    board->batt_smooth_alpha = 0.08f;
    board->mic_base_gain_q10 = 1024;
    board->mic_boost_gain_q10 = 3072;
    board->mic_cut_gain_q10 = 512;
#endif
}

/**
 * Return the currently active logical communication channel.
 *
 * PTT mode uses the user-selected channel. Kid mode is locked to channel 1 and
 * sets a flag so normal PTT traffic and kid-mode traffic do not mix.
 * Callers must hold s_state_lock because this reads UI state.
 */
static bool active_comm_locked(uint8_t *logical_channel, uint8_t *flags)
{
    if (s_app.ui_mode == MODE_KID) {
        if (logical_channel) {
            *logical_channel = KID_CHANNEL;
        }
        if (flags) {
            *flags = FLAG_KID;
        }
        return true;
    }

    if (s_app.ui_mode == MODE_PTT) {
        if (logical_channel) {
            *logical_channel = (uint8_t)s_app.current_channel;
        }
        if (flags) {
            *flags = 0;
        }
        return true;
    }

    return false;
}
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
void app_main(void)
{
    esp_err_t err = nvs_flash_init();
    if (err == ESP_ERR_NVS_NO_FREE_PAGES || err == ESP_ERR_NVS_NEW_VERSION_FOUND) {
        ESP_ERROR_CHECK(nvs_flash_erase());
        err = nvs_flash_init();
    }
    ESP_ERROR_CHECK(err);

    board_config_init(&s_board);
    gpio_init_inputs_outputs();
    button_init(&s_ok_btn, OK_PIN, 70);
    button_init(&s_left_btn, s_board.top_left_pin, 70);
    button_init(&s_right_btn, s_board.top_right_pin, 70);
    button_init(&s_bl_btn, BOT_LEFT_PIN, 70);
    button_init(&s_br_btn, BOT_RIGHT_PIN, 70);

    s_state_lock = xSemaphoreCreateMutex();
    if (s_state_lock == NULL) {
        ESP_LOGE(TAG, "state mutex alloc failed");
        return;
    }

    jitter_init(&s_jitter);
    if (s_jitter.mutex == NULL) {
        ESP_LOGE(TAG, "jitter mutex alloc failed");
        return;
    }

    /* Mount field-test storage before the rest of the app starts so the boot
     * gesture can dump stored logs without needing Wi-Fi or I2S to initialize. */
    if (field_log_init() == ESP_OK) {
        field_log_dump_if_requested();
    }

    esp_err_t adc_err = adc_init_all();
    if (adc_err != ESP_OK) {
        ESP_LOGW(TAG, "adc init failed, using safe defaults: %s", esp_err_to_name(adc_err));
    }

    if (walkie_display_init(&s_display, OLED_SDA, OLED_SCL) == ESP_OK) {
        walkie_display_show_splash(&s_display);
    }

    xSemaphoreTake(s_state_lock, portMAX_DELAY);
    set_state_defaults();
    xSemaphoreGive(s_state_lock);

    if (walkie_display_ready(&s_display)) {
        walkie_ui_snapshot_t snapshot;
        xSemaphoreTake(s_state_lock, portMAX_DELAY);
        state_copy_snapshot_locked(&snapshot, xTaskGetTickCount(), esp_timer_get_time() / 1000);
        xSemaphoreGive(s_state_lock);
        walkie_display_redraw(&s_display, &snapshot);
    }

    esp_err_t wifi_err = wifi_init_for_espnow();
    if (wifi_err != ESP_OK) {
        ESP_LOGW(TAG, "wifi init failed, radio disabled: %s", esp_err_to_name(wifi_err));
    } else {
        esp_err_t now_err = espnow_init_peer();
        if (now_err != ESP_OK) {
            ESP_LOGW(TAG, "esp-now init failed, radio disabled: %s", esp_err_to_name(now_err));
        }
    }

    esp_err_t i2s_err = i2s_init_pair();
    if (i2s_err != ESP_OK) {
        ESP_LOGW(TAG, "i2s init failed, audio disabled: %s", esp_err_to_name(i2s_err));
    }

    uint8_t my_mac[6];
    esp_read_mac(my_mac, ESP_MAC_WIFI_STA);
    char my_mac_text[18];
    char peer_mac_text[18];
    char expect_mac_text[18];
    ESP_LOGI(TAG, "Device role: %s", s_board.label);
    ESP_LOGI(TAG, "STA MAC: %s", mac_to_str(my_mac, my_mac_text, sizeof(my_mac_text)));
    ESP_LOGI(TAG, "Expected MAC: %s", mac_to_str(s_board.self_mac, expect_mac_text, sizeof(expect_mac_text)));
    ESP_LOGI(TAG, "Peer MAC: %s", mac_to_str(s_board.peer_mac, peer_mac_text, sizeof(peer_mac_text)));
    ESP_LOGI(TAG, "RF channel: %d", CONFIG_WALKIE_RF_CHANNEL);
    ESP_LOGI(TAG, "ADC ready: %s", s_adc_ready ? "yes" : "no");
    ESP_LOGI(TAG, "Radio ready: %s", s_radio_ready ? "yes" : "no");
    ESP_LOGI(TAG, "Audio TX ready: %s", s_i2s_tx_ready ? "yes" : "no");
    ESP_LOGI(TAG, "Audio RX ready: %s", s_i2s_rx_ready ? "yes" : "no");

    xTaskCreatePinnedToCore(control_task, "walkie_control", 8192, NULL, 7, NULL, 1);
    if (s_field_log_ready && s_field_log_queue != NULL) {
        /* Low priority: if flash is slow, audio/radio/control work wins. */
        xTaskCreatePinnedToCore(field_log_task, "walkie_fieldlog", 4096, NULL, 2, NULL, 0);
    }
    xTaskCreatePinnedToCore(capture_task, "walkie_capture", 8192, NULL, 5, NULL, 0);
    xTaskCreatePinnedToCore(playback_task, "walkie_playback", 8192, NULL, 5, NULL, 1);
}

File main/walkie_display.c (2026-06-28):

#include "walkie_display.h"

#include <ctype.h>
#include <stdio.h>
#include <string.h>

#include "esp_check.h"
#include "esp_log.h"
#include "freertos/FreeRTOS.h"
#include "freertos/task.h"

/*
 * Minimal SSD1306 renderer.
 *
 * The rest of the firmware builds a walkie_ui_snapshot_t, and this file turns
 * that snapshot into pixels. Keeping drawing code here means the control/audio
 * tasks never need to know about font glyphs, framebuffer pages, or I2C flushes.
 */

static const char *TAG = "walkie_display";

#define OLED_WIDTH 128
#define OLED_HEIGHT 64
#define OLED_PAGES (OLED_HEIGHT / 8)

typedef enum {
    FONT_SMALL = 0,
    FONT_BODY,
    FONT_LARGE,
} font_kind_t;

typedef struct {
    char ch;
    uint8_t cols[5];
} glyph5x7_t;

static const glyph5x7_t s_font[] = {
    {' ', {0x00, 0x00, 0x00, 0x00, 0x00}},
    {'.', {0x00, 0x60, 0x60, 0x00, 0x00}},
    {':', {0x00, 0x36, 0x36, 0x00, 0x00}},
    {'<', {0x08, 0x14, 0x22, 0x41, 0x00}},
    {'>', {0x41, 0x22, 0x14, 0x08, 0x00}},
    {'+', {0x08, 0x08, 0x3E, 0x08, 0x08}},
    {'-', {0x08, 0x08, 0x08, 0x08, 0x08}},
    {'%', {0x63, 0x13, 0x08, 0x64, 0x63}},
    {'0', {0x3E, 0x51, 0x49, 0x45, 0x3E}},
    {'1', {0x00, 0x42, 0x7F, 0x40, 0x00}},
    {'2', {0x42, 0x61, 0x51, 0x49, 0x46}},
    {'3', {0x21, 0x41, 0x45, 0x4B, 0x31}},
    {'4', {0x18, 0x14, 0x12, 0x7F, 0x10}},
    {'5', {0x27, 0x45, 0x45, 0x45, 0x39}},
    {'6', {0x3C, 0x4A, 0x49, 0x49, 0x30}},
    {'7', {0x01, 0x71, 0x09, 0x05, 0x03}},
    {'8', {0x36, 0x49, 0x49, 0x49, 0x36}},
    {'9', {0x06, 0x49, 0x49, 0x29, 0x1E}},
    {'A', {0x7E, 0x11, 0x11, 0x11, 0x7E}},
    {'B', {0x7F, 0x49, 0x49, 0x49, 0x36}},
    {'C', {0x3E, 0x41, 0x41, 0x41, 0x22}},
    {'D', {0x7F, 0x41, 0x41, 0x22, 0x1C}},
    {'E', {0x7F, 0x49, 0x49, 0x49, 0x41}},
    {'F', {0x7F, 0x09, 0x09, 0x09, 0x01}},
    {'G', {0x3E, 0x41, 0x49, 0x49, 0x7A}},
    {'H', {0x7F, 0x08, 0x08, 0x08, 0x7F}},
    {'I', {0x00, 0x41, 0x7F, 0x41, 0x00}},
    {'J', {0x20, 0x40, 0x41, 0x3F, 0x01}},
    {'K', {0x7F, 0x08, 0x14, 0x22, 0x41}},
    {'L', {0x7F, 0x40, 0x40, 0x40, 0x40}},
    {'M', {0x7F, 0x02, 0x0C, 0x02, 0x7F}},
    {'N', {0x7F, 0x04, 0x08, 0x10, 0x7F}},
    {'O', {0x3E, 0x41, 0x41, 0x41, 0x3E}},
    {'P', {0x7F, 0x09, 0x09, 0x09, 0x06}},
    {'Q', {0x3E, 0x41, 0x51, 0x21, 0x5E}},
    {'R', {0x7F, 0x09, 0x19, 0x29, 0x46}},
    {'S', {0x46, 0x49, 0x49, 0x49, 0x31}},
    {'T', {0x01, 0x01, 0x7F, 0x01, 0x01}},
    {'U', {0x3F, 0x40, 0x40, 0x40, 0x3F}},
    {'V', {0x1F, 0x20, 0x40, 0x20, 0x1F}},
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
};

/**
 * Look up a 5x7 bitmap glyph for a printable character.
 *
 * The font table is uppercase-only, so lowercase input is normalized. Unknown
 * characters render as spaces rather than drawing garbage.
 */
static const uint8_t *glyph_for_char(char ch)
{
    char upper = (char)toupper((unsigned char)ch);

    for (size_t i = 0; i < sizeof(s_font) / sizeof(s_font[0]); ++i) {
        if (s_font[i].ch == upper) {
            return s_font[i].cols;
        }
    }

    return s_font[0].cols;
}

/**
 * Return pixel scale for a font size.
 *
 * FONT_SMALL and FONT_BODY use native 5x7 pixels. FONT_LARGE doubles both axes
 * for splash/scanning screens where bigger text is useful.
 */
static int font_scale(font_kind_t font)
{
    if (font == FONT_LARGE) {
        return 2;
    }
    return 1;
}

/**
 * Return horizontal cursor advance for one character.
 *
 * The glyph itself is 5 columns wide; the sixth column is spacing. Scaling is
 * included so layout helpers can measure text consistently.
 */
static int font_advance(font_kind_t font)
{
    return 6 * font_scale(font);
}

/**
 * Send one or more command/data bytes to the SSD1306 over I2C.
 *
 * The small tx buffer keeps stack usage low. Large framebuffer writes are split
 * into 16-byte chunks because each I2C transfer includes a control byte.
 */
static esp_err_t oled_send_block(walkie_display_t *display, uint8_t control, const uint8_t *data, size_t len)
{
    uint8_t tx[17];

    if (!display || !display->dev) {
        return ESP_ERR_INVALID_STATE;
    }

    tx[0] = control;
    while (len > 0) {
        size_t chunk = len > 16 ? 16 : len;
        memcpy(&tx[1], data, chunk);
        esp_err_t err = i2c_master_transmit(display->dev, tx, chunk + 1, 1000);
        if (err != ESP_OK) {
            return err;
        }
        data += chunk;
        len -= chunk;
    }

    return ESP_OK;
}

/**
 * Send SSD1306 command bytes.
 *
 * Control byte 0x00 tells the display controller that the following bytes are
 * commands, not framebuffer data.
 */
static esp_err_t oled_send_cmds(walkie_display_t *display, const uint8_t *cmds, size_t len)
{
    return oled_send_block(display, 0x00, cmds, len);
}

/**
 * Send SSD1306 framebuffer data bytes.
 *
 * Control byte 0x40 selects data mode. oled_flush() calls this one page at a
 * time to update the visible display.
 */
static esp_err_t oled_send_data(walkie_display_t *display, const uint8_t *data, size_t len)
{
    return oled_send_block(display, 0x40, data, len);
}

/**
 * Clear the local 1-bit framebuffer.
 *
 * Nothing changes on the OLED until oled_flush() sends the framebuffer pages.
 */
static void fb_clear(walkie_display_t *display)
{
    memset(display->framebuffer, 0, sizeof(display->framebuffer));
}

/**
 * Set or clear one framebuffer pixel with bounds checking.
 *
 * The SSD1306 framebuffer is arranged as vertical 8-pixel pages, so y selects a
 * bit inside one byte and x selects the byte column.
 */
static void fb_set_pixel(walkie_display_t *display, int x, int y, bool on)
{
    if (x < 0 || x >= OLED_WIDTH || y < 0 || y >= OLED_HEIGHT) {
        return;
    }

    uint8_t *cell = &display->framebuffer[x + ((y / 8) * OLED_WIDTH)];
    uint8_t mask = (uint8_t)(1U << (y & 7));

    if (on) {
        *cell |= mask;
    } else {
        *cell &= (uint8_t)~mask;
    }
}

/**
 * Fill a rectangle in the local framebuffer.
 *
 * This simple pixel-loop renderer is fast enough for a 128x64 monochrome OLED
 * and keeps all higher-level drawing primitives easy to reason about.
 */
static void fb_fill_rect(walkie_display_t *display, int x, int y, int w, int h, bool on)
{
    for (int yy = 0; yy < h; ++yy) {
        for (int xx = 0; xx < w; ++xx) {
            fb_set_pixel(display, x + xx, y + yy, on);
        }
    }
}

/**
 * Draw a one-pixel rectangular outline.
 *
 * Used for cards, menu boxes, signal meters, battery outline, and status boxes.
 */
static void fb_draw_frame(walkie_display_t *display, int x, int y, int w, int h)
{
    if (w <= 0 || h <= 0) {
        return;
    }

    fb_fill_rect(display, x, y, w, 1, true);
    fb_fill_rect(display, x, y + h - 1, w, 1, true);
    fb_fill_rect(display, x, y, 1, h, true);
    fb_fill_rect(display, x + w - 1, y, 1, h, true);
}
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
